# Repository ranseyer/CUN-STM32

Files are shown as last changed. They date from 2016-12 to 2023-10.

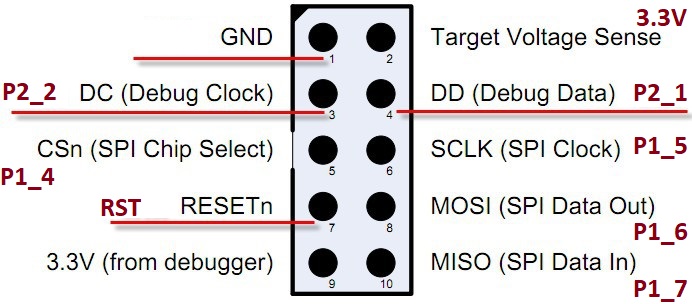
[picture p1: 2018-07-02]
HW-MAPLE-Large/AddOns/RasPi-UART__Zigbee-CC2530/Zigbee/smartrf04eb-pinout.jpg

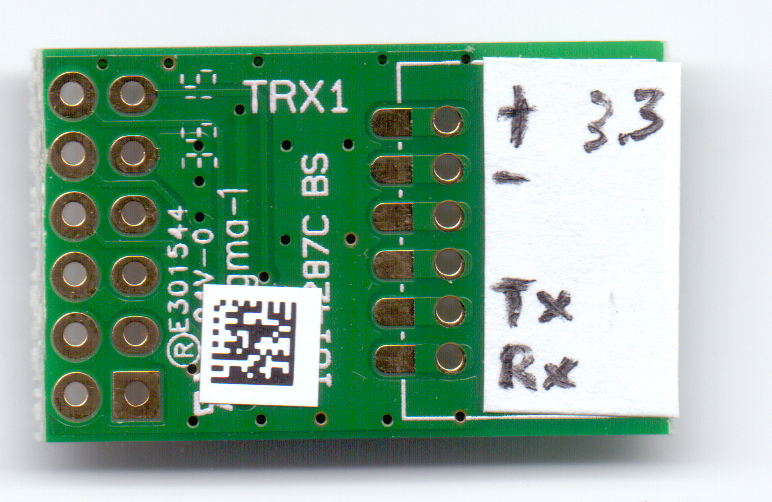
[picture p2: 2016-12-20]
Datasheets/HM_MOD_UART-Pinout.png

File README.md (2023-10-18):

View this project on [CADLAB.io](https://cadlab.io/project/1060). 

# CUN-STM32
The MAPLE-CUL is an ARM based RF Transceiver w/wo LAN for 433 or 868 MHz

- based on the STM32 / MAPLE Microcontroller
- Up to 4 Transceiver-Modules
- 2 Free UARTs for other AddOns / Transceiver or so
- 1 UART for WLAN Connection or debugging

-a lot of HW-AddOns are availble

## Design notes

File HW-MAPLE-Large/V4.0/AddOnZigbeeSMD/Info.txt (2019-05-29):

CC2530 Drahtlose Modul Zigbee Modul SZ1Zigbee 3,0-3,6 v 2,405-2,485 ghz
z.B. von Red Yellow Store
https://de.aliexpress.com/item/1861120386.html

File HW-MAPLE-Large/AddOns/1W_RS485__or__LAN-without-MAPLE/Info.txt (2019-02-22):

This AddOn hast two main functions:

Using Maple-CUL-AddOns without MAPLE-CUL
========================================
A) Base: USR-TCP232-E2 wit two UARTs or hopefully T2 (only one UART)
Important: This Board with LAN Module comes on top of all others...

MAPLE-CUL AddOn for OneWire and RS485
A) Onewire with DS2480 at the last UART of the MAPLE (UART2 can handle 5V without Levelshifter)
B) RS485 via Arduino and MAX487 or similar

Status: Not tested.

Todo: Check of separation of the connectors for RS485 and OneWire for parallel usage...

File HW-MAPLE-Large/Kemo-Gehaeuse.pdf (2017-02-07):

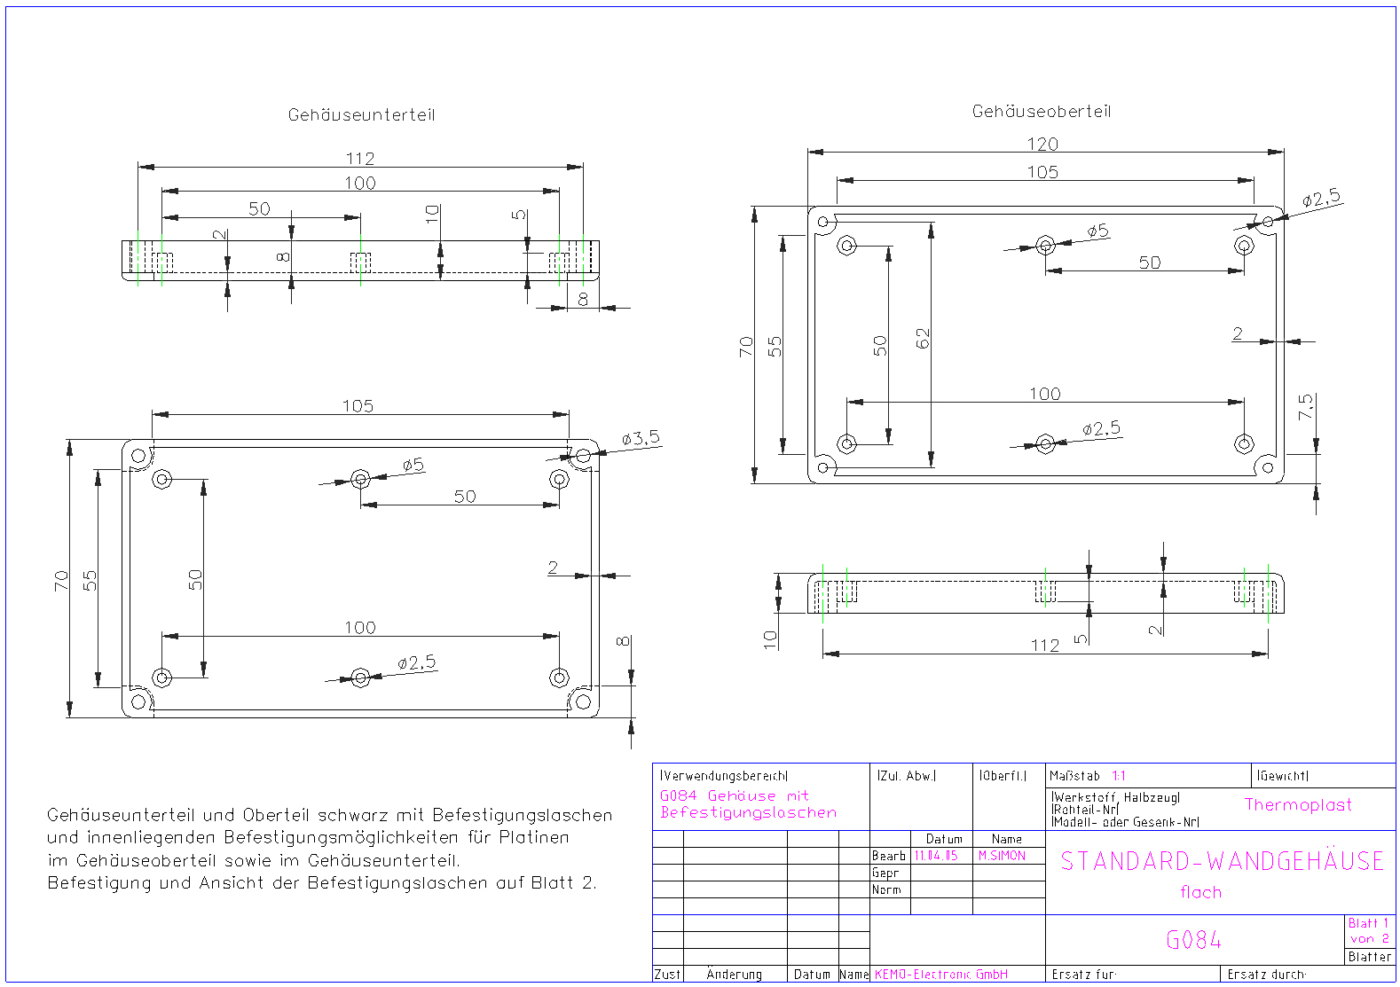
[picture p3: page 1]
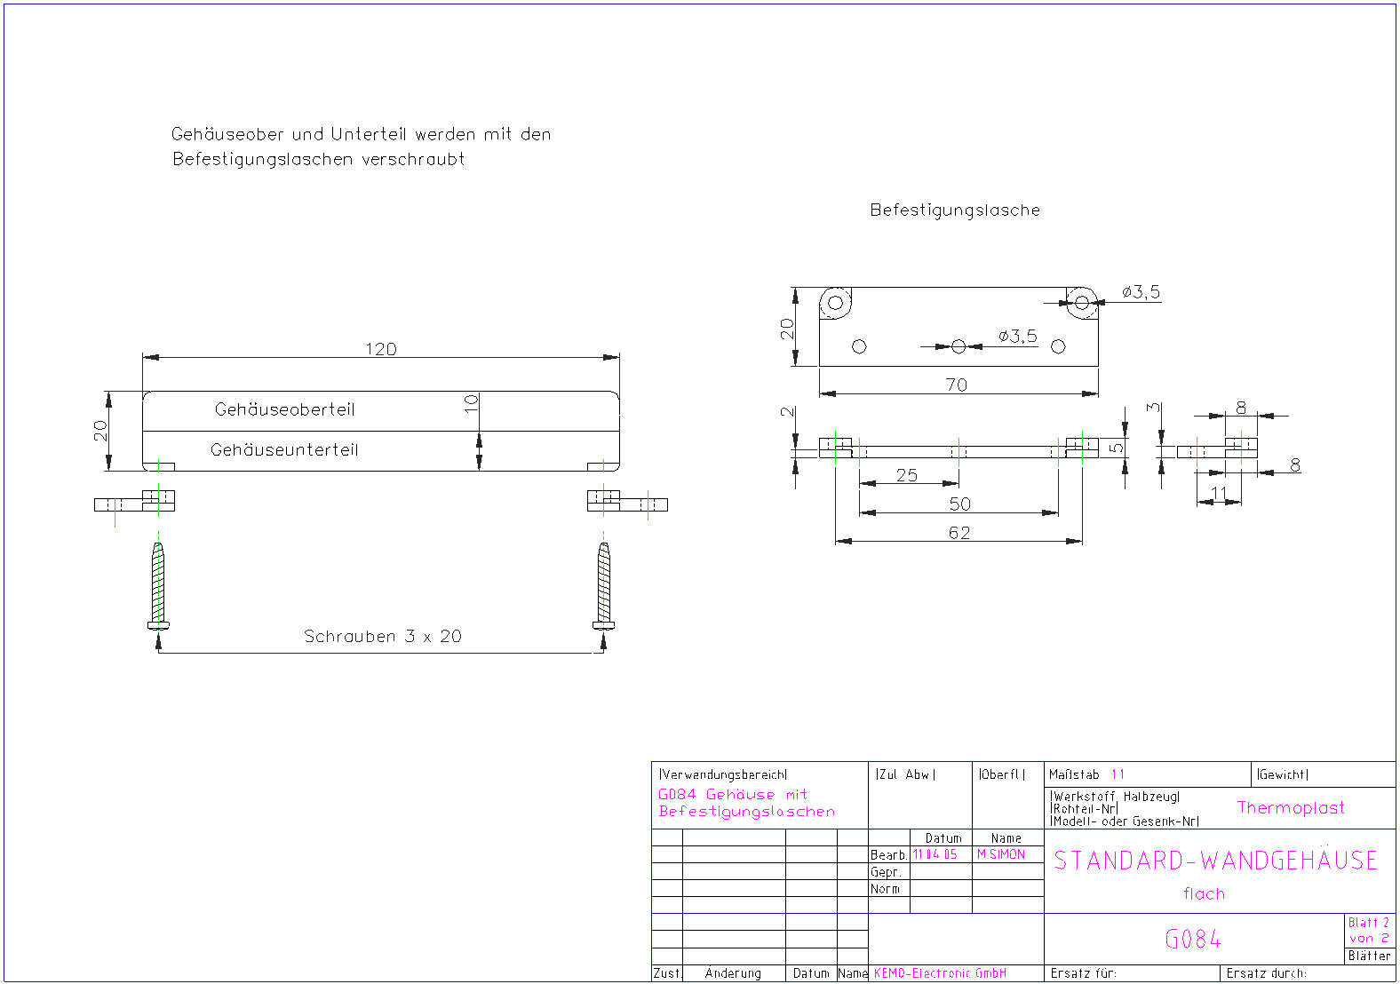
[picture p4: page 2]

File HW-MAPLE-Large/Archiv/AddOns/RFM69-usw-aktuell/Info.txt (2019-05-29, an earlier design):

Bei V1.4 gehen rx und TX auf verschiedene UARTs. Es muss daher einer der beiden Pins an den RX/TX-Sel Jumpern auf den anderen UART gelegt werden, so dass der Arduino nur mit einem UART kommuniziert.

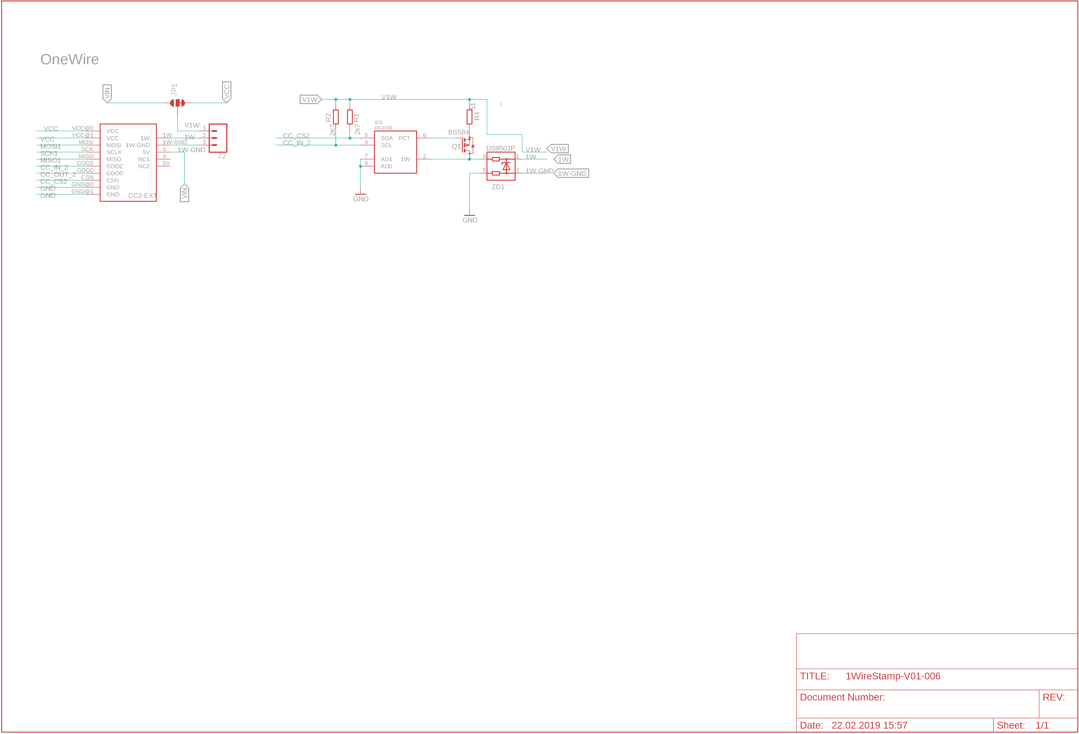
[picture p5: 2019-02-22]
HW-MAPLE-Large/Stamps/1Wire-Stamp/Schematic.png

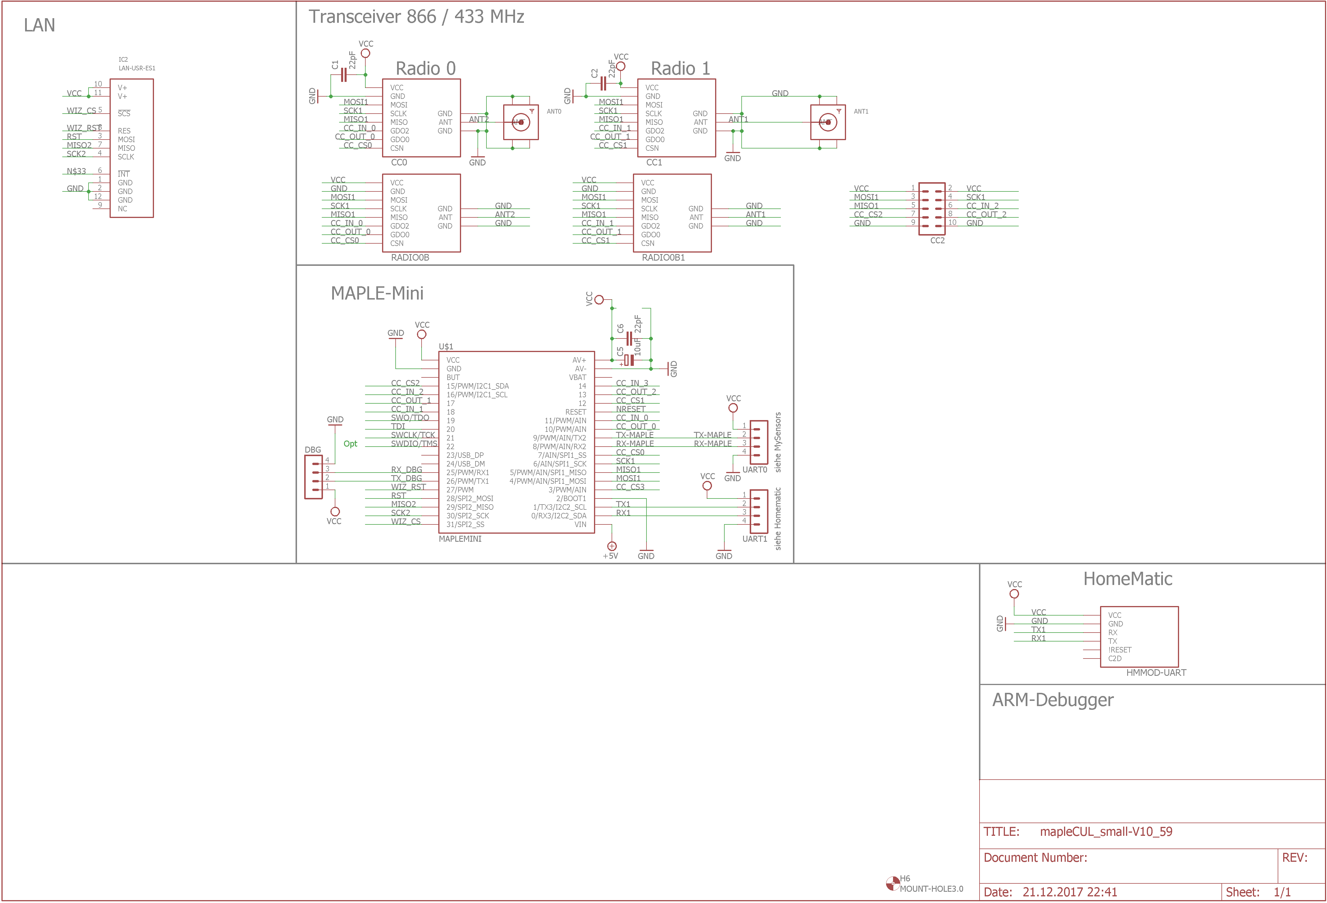
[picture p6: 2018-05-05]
HW-MAPLE-Small/Schematic-V10.png

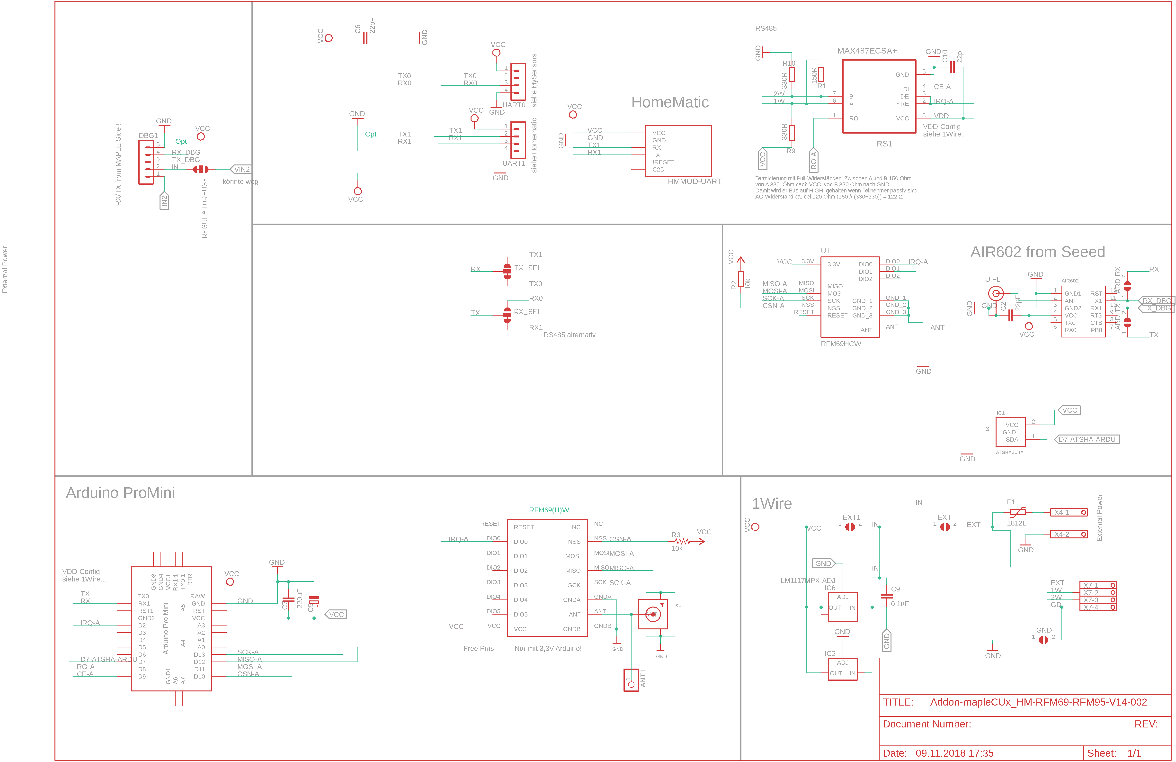
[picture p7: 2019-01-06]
HW-MAPLE-Large/AddOns/RFM69-usw-aktuell/schematic.png

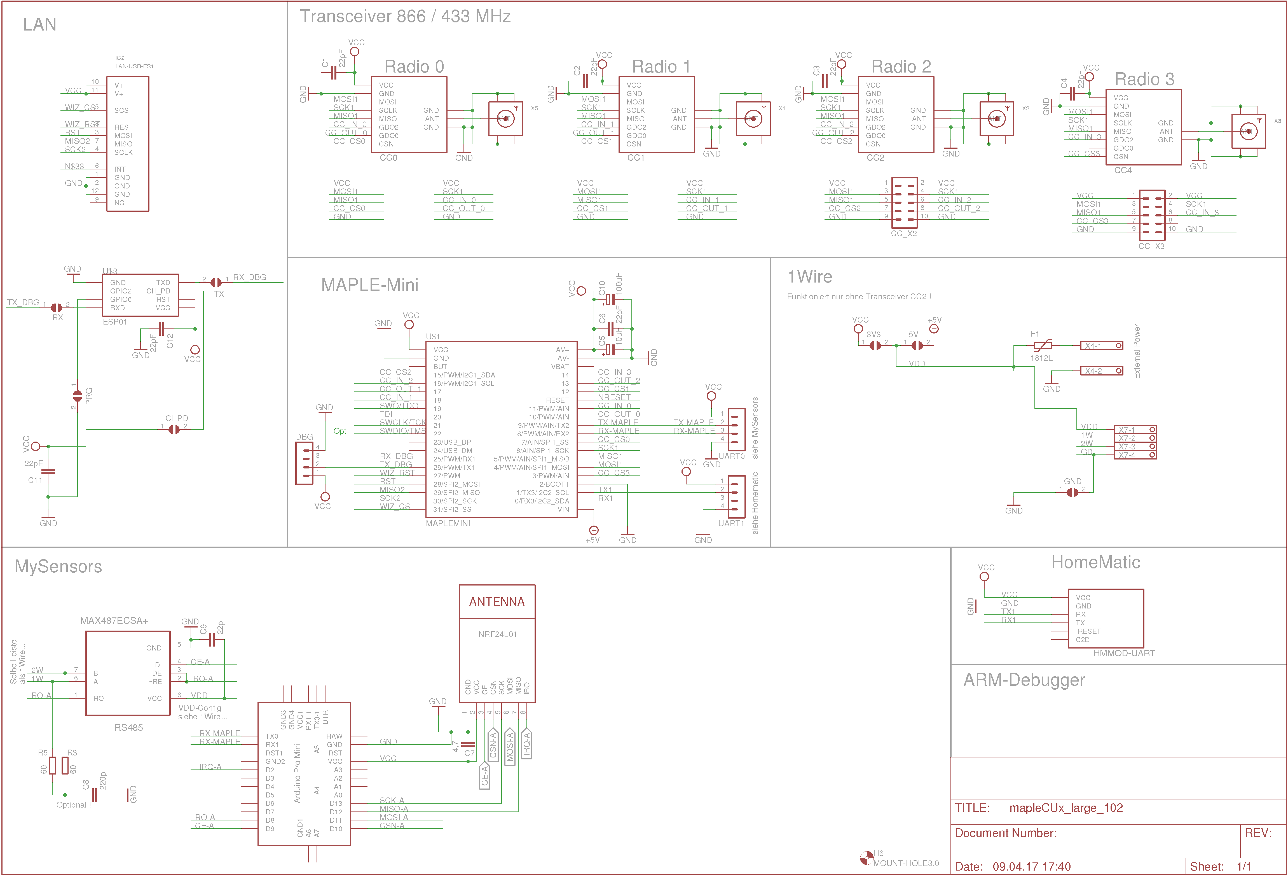
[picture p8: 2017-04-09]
HW-MAPLE-Large/Schematic-V102.png

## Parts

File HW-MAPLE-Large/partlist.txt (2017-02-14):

Partlist

Exported from mapleCUx_large_041.sch at 14.02.17 21:07

EAGLE Version 7.3.0 Copyright (c) 1988-2015 CadSoft

Assembly variant: 

Part       Value             Device            Package            Library         Sheet

C1         22pF              C-EUC0805         C0805              rcl             1
C2         22pF              C-EUC0805         C0805              rcl             1
C3         22pF              C-EUC0805         C0805              rcl             1
C4         22pF              C-EUC0805         C0805              rcl             1
C5         10uF              C-EUC1210         C1210              rcl             1
C6         22pF              C-EUC0805         C0805              rcl             1
C7         4,7               C-EUC1210         C1210              rcl             1
C31        100n              C-EUC0805         C0805              rcl             1
C32        100n              C-EUC0805         C0805              rcl             1
CC0        CC1101_MODULE1SMD CC1101_MODULE1SMD CC1101_MODULE1_SMD wireless        1
CC1        CC1101_MODULE1SMD CC1101_MODULE1SMD CC1101_MODULE1_SMD wireless        1
CC2        CC1101_MODULE1SMD CC1101_MODULE1SMD CC1101_MODULE1_SMD wireless        1
CC4        CC1101_MODULE1SMD CC1101_MODULE1SMD CC1101_MODULE1_SMD wireless        1
CC_X0                        MA05-2            MA05-2             con-lstb        1
CC_X1                        MA05-2            MA05-2             con-lstb        1
CC_X2                        MA05-2            MA05-2             con-lstb        1
CC_X4                        MA05-2            MA05-2             con-lstb        1
CTX-DB     1365-10           1365-10           1365-10            con-leotronics  1
DBG                          MA04-1            MA04-1             con-lstb        1
IC31       ATMEGA168-TQFP    ATMEGA168-TQFP    TQFP32-08          atmel           1
LED32                        LEDCHIPLED_0805   CHIPLED_0805       led             1
NRF24L01+  NRF24L01+         WIRELESS-NRF24L01 WIRELESS-NRF24L01  diy-modules     1
R32        1k                R-EU_R0805        R0805              rcl             1
R34                          R-EU_R0805        R0805              rcl             1
U$1        MAPLEMINI         MAPLEMINI         20-DIP             maplemini-small 1
U$2        ABK-PRO-MINI      ABK-PRO-MINI      ABK-PRO-MINI       Arduino-clone   1
UART0                        MA04-1            MA04-1             con-lstb        1
UART1                        MA04-1            MA04-1             con-lstb        1
W5100                        FE05-2            FE05-2             con-lsta        1
W5500NIREN                   MA05-2            MA05-2             con-lstb        1
X1         SMA               SMA               SMA                sma             1
X2         SMA               SMA               SMA                sma             1
X3         SMA               SMA               SMA                sma             1
X4         SMA               SMA               SMA                sma             1
X31        M03X2             M03X2             2X03-1.27MM_SMD    mechanics       1

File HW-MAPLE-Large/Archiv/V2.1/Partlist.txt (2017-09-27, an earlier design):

Partlist

Exported from mapleCUx_large_210.brd at 27.09.17 18:10

EAGLE Version 7.3.0 Copyright (c) 1988-2015 CadSoft

Assembly variant: 

Part       Value               Package            Library                     Position (mil)        Orientation

3V3                            SJ                 jumper                      (3825 750)            MR180
5V                             SJ                 jumper                      (3825 900)            MR0
ANT        MICRO RF            1X01               SparkFun-Connectors         (1900 200)            R0
C1         22pF                C0805              rcl                         (675 1100)            R0
C2         22pF                C0805              rcl                         (1842.75591 907.28346) R90
C3         22pF                C0805              rcl                         (2714.37008 1725)     MR180
C4         22pF                C0805              rcl                         (2690.31496 1075)     R0
C5         220uF               E5-8,5             rcl                         (2925 650)            R270
C6         22pF                C0805              rcl                         (175 2189.37008)      R180
C7                             C1812              rcl                         (2850 650)            R90
C8         220p                C0805              rcl                         (2481.69291 1907.67717) MR90
C9         22p                 C0805              rcl                         (3025 1940.94488)     MR270
C11        22pF                C0805              rcl                         (852.91339 887.59843) R270
C12        22pF                C0805              rcl                         (3650 1100)           R180
C14        30pf                0805               doug                        (800 200)             MR270
C15        30pf                0805               doug                        (800 375)             MR90
C31        100n                C0805              rcl                         (850 575)             MR0
C32        100n                C0805              rcl                         (1000 550)            MR270
CC0        CC1101              CC1101_MODULE1_SMD wireless                    (175 975)             R270
CC1        CC1101_MODULE1SMD   CC1101_MODULE1_SMD wireless                    (3150 975)            R270
CC2        CC1101_MODULE1SMD   CC1101_MODULE1_SMD wireless                    (1175 975)            R270
CC2-EXT    CC1101_MODULE3_DIL  CC1101_MODULE3_DIL wireless                    (1254.72441 1251.5748) R270
CC3        CC1101_MODULE1SMD   CC1101_MODULE1_SMD wireless                    (2175 975)            R270
CC3-EXT    CC1101_MODULE3_DIL  CC1101_MODULE3_DIL wireless                    (1944.68504 1256.88976) R270
CHPD                           SJ                 jumper                      (1850 600)            MR180
DBG                            MA04-1             con-lstb                    (1400 1650)           R270
F1         1812L               1812L              ptc-littlefuse              (3760 1745)           MR180
F2         1812L               1812L              ptc-littlefuse              (3850 525)            R270
GND                            SJ                 jumper                      (3825 1025)           MR180
HMMOD-UART HM-MOD-UARTDIL      HM-MOD-UART-DIL    wireless                    (3090 1485)           MR90
IC2        LAN-USR-ES1         USR-ES1            Martin-Communication        (330 1645)            R90
IC31       ATMEGA168-TQFP      TQFP32-08          atmel                       (400 550)             MR90
L1                             WE-KI_0805A        EAGLE-EMC_COMPONENTS-rev17a (2204.72441 2165.35433) R270
NRF24L01+  NRF24L01+           WIRELESS-NRF24L01  diy-modules                 (2600 1800)           R0
PRG                            SJ                 jumper                      (1850 750)            MR0
R1                             SJ_2               jumper                      (1025 1125)           MR90
R2         10k                 0805               doug                        (825 750)             MR90
R3         60                  R0805              rcl                         (3275 1250)           MR270
R4         1M                  0805               doug                        (1025 150)            MR0
R5         60                  R0805              rcl                         (3450 1275)           MR180
R34                            R0805              rcl                         (975 725)             MR180
RADIO0B    CC1101_MODULE1SMALL CC1101_MODULE1_SMD Martin-Communication        (240 815)             R270
RADIO1B    CC1101_MODULE1SMALL CC1101_MODULE1_SMD Martin-Communication        (3210 820)            R270
RADIO2B    CC1101_MODULE1SMALL CC1101_MODULE1_SMD Martin-Communication        (1240 820)            R270
RADIO3B    CC1101_MODULE1SMALL CC1101_MODULE1_SMD Martin-Communication        (2240 820)            R270
RS485      MAX487ECSA+         SOIC127P600X175-8N Maxim_By_element14_Batch_1  (2760.62992 1915.94488) MR180
RX                             SJ                 jumper                      (2050 750)            MR180
T1                             SJ_2               jumper                      (900 1125)            MR90
TX                             SJ                 jumper                      (2050 600)            MR180
U$1        MAPLEMINI           20-DIP             maplemini-small             (997.5 1645.62992)    R0
U$2        ABK-PRO-MINI        ABK-PRO-MINI       Arduino-clone               (3200 2002.79528)     R270
U$3        ESP01               ESP01              esp8266modules              (3250 1150)           R270
U1         RFM69HCW            RFM69HCW-XXXS2     doug                        (1425 600)            MR270
UART0                          MA04-1             con-lstb                    (1475 2200)           R0
UART1                          MA04-1             con-lstb                    (950 2200)            R0
X1                             SMA_EDGELAUNCH     adafruit                    (3425 0)              R90
X2                             SMA_EDGELAUNCH     adafruit                    (1400 0)              R90
X3                             SMA_EDGELAUNCH     adafruit                    (2400 0)              R90
X4         1751248             1751248            con-phoenix-350             (3800 1975)           R270
X5                             SMA_EDGELAUNCH     adafruit                    (400 0)               R90
X7         1751264             1751264            con-phoenix-350             (3800 1375)           R270
X8                             SMA_EDGELAUNCH_UFL adafruit                    (1900 0)              R90
X31        M03X2               2X03-1.27MM_SMD    mechanics                   (925 125)             R90
Y2         8MHZ                CRYSTAL-TXC-7A     SparkFun-FreqCtrl           (1000 325)            MR270

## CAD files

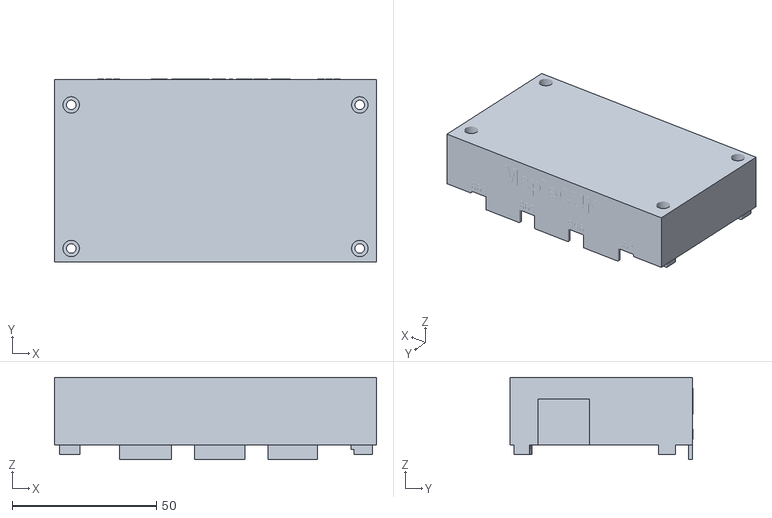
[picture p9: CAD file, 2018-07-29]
HW-MAPLE-Large/Gehaeuse/by_Eistee/MapleCUN_top.stl
111.7 x 63.4 x 28.6

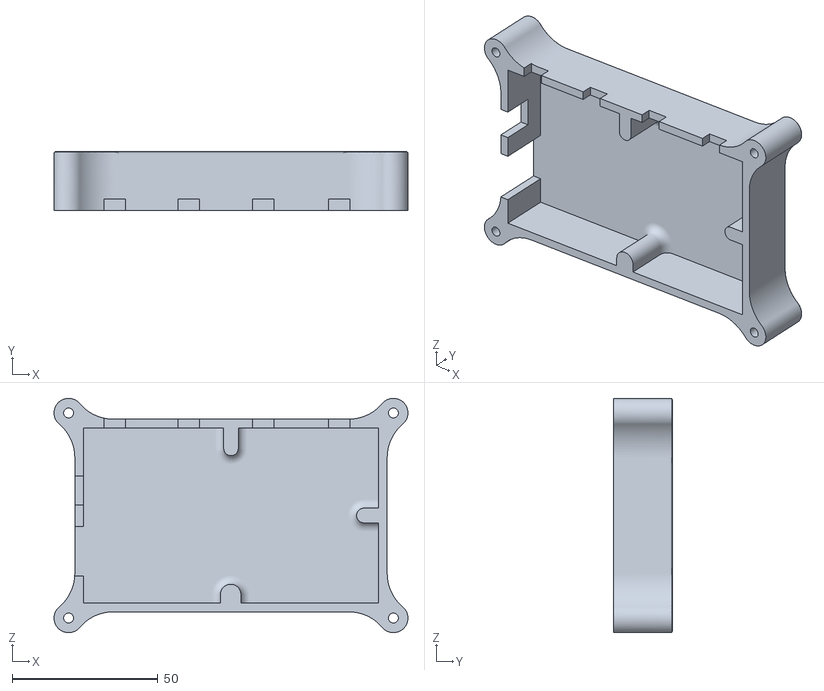
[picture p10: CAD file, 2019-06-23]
HW-MAPLE-Large/Gehaeuse/Gloob/Top_v28.stl
121.2 x 20.1 x 80.2

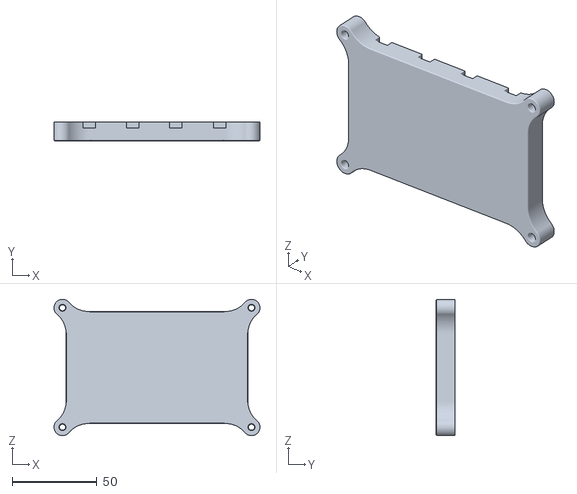
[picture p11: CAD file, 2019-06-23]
HW-MAPLE-Large/Gehaeuse/Gloob/Bottom_v28.stl
121.2 x 11.0 x 80.2

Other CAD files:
HW-MAPLE-Large/Gehaeuse/Gloob/Top-FreeCAD-Import-V28.FCStd
HW-MAPLE-Large/Gehaeuse/Gloob/Top_v28_without_ethernet.stl
HW-MAPLE-Large/Gehaeuse/by_Eistee/MapleCUN_Gehäuse.f3d

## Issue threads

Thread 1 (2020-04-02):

AddOnArduino-RFMx RX/TX vertauscht

matztam, 2020-04-02:
Folgende Platinen kommen zum Einsatz:
- mapleCUx_large_4.1-018.brd
- V4-MySensors-LoRa-V006.brd

Auf dem AddOnArduino-RFMx ist ein Arduino Pro Mini (ATmega 328p 5V/16MHz) verlötet.

Damit die vom Addon ausgegebenen Daten auch vom MapleCun übertragen wurden, musste ich RX und TX mit einem Kabel vertauschen/kreuzen. Ich habe es an beiden UARTs getestet.

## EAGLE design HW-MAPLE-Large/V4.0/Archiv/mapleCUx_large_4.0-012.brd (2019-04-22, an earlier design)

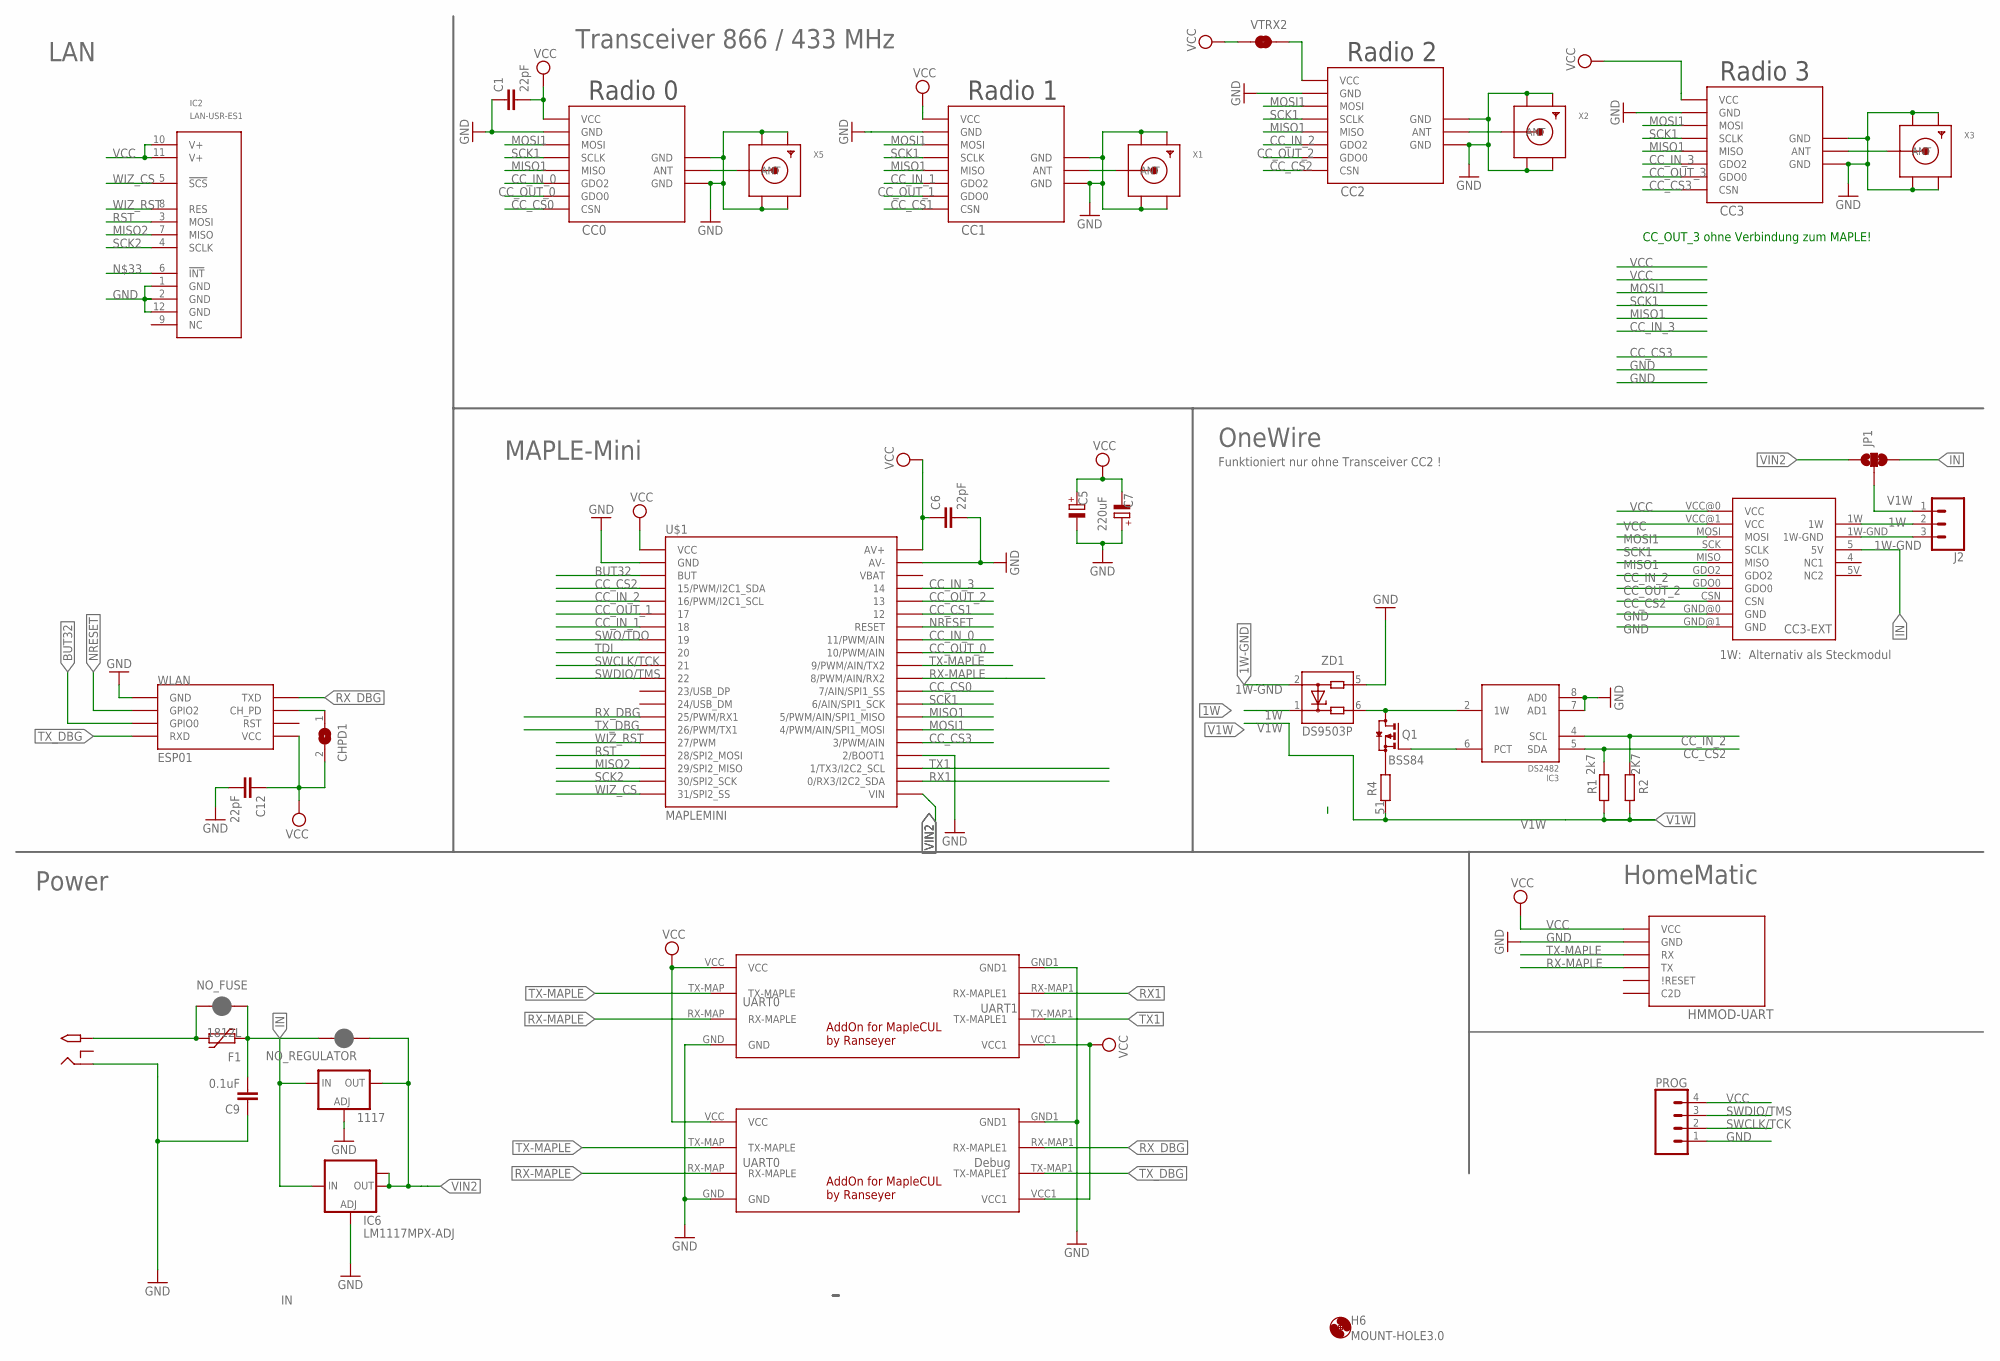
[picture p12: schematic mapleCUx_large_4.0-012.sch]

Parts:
1117: LD117ADT50TR; DPACK
C1, C6, C12: 22pF; C0805
C5: 220uF; E5-8,5
C7: CPOL-EUSMCE; SMC_E
C9: 0.1uF; C1206
CC0: CC1101; CC1101_MODULE1_SMD
CC1, CC2, CC3: CC1101_MODULE1SMD; CC1101_MODULE1_SMD
CC3-EXT: ONEWIRE-MODULE; ONEWIRE_CC1101_MODULE3_DIL
CHPD1: SJ
F1: 1812L
H6: MOUNT-HOLE3.0; 3,0
HMMOD-UART: HM-MOD-UARTDIL; HM-MOD-UART-DIL
IC2: LAN-USR-ES1; USR-ES1
IC3: DS2482; SO08
IC6: LM1117MPX-ADJ; SOT223
J2: CONN_03LONGPADS; 1X03_LONGPADS
JP1: JUMPER-SMT_3_1-NC_TRACE_SILK; SMT-JUMPER_3_1-NC_TRACE_SILK
NO_FUSE: JUMPER-SMT_2_NC_PASTE_NO-SILK; SMT-JUMPER_2_NC_PASTE_NO-SILK
NO_REGULATOR: JUMPER-SMT_2_NC_PASTE_NO-SILK; SMT-JUMPER_2_NC_PASTE_NO-SILK
PROG: CONN_04LOCK; 1X04_LOCK
Q1: BSS84; SOT23
R1: 2k7; R0805
R2: 2K7; R0805
R4: 51; R0805
U$1: MAPLEMINI; 20-DIP
U$2: 2.1MMJACKTHM; PJ-102A
U$3, U$4: MAPLE-CUL-ADDON-V01; MAPLE-CUL-V01
VTRX2: JUMPER-SMT_2_NC_TRACE_SILK; SMT-JUMPER_2_NC_TRACE_SILK
WLAN: ESP01
X1, X2, X3, X5: SMACONNECTOR_EDGE; SMA_EDGELAUNCH
ZD1: DS9503P; TSOC6

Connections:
1W: CC3-EXT.1W, J2.2, ZD1.1
1W-GND: CC3-EXT.1W-GND, J2.3, ZD1.2
ANT0: CC0.ANT, X5.P (ANT)
ANT1: CC1.ANT, X1.P (ANT)
ANT2: CC2.ANT, X2.P (ANT)
ANT3: CC3.ANT, X3.P (ANT)
BUT32: U$1.3 (BUT), WLAN.GPIO0
CC_CS0: CC0.CSN, U$1.29 (7/AIN/SPI1_SS)
CC_CS1: CC1.CSN, U$1.35 (12)
CC_CS2: CC2.CSN, CC3-EXT.CSN, IC3.5 (SDA), R1.2, U$1.4 (15/PWM/I2C1_SDA)
CC_CS3: CC3.CSN, U$1.25 (3/PWM/AIN)
CC_IN_0: CC0.GDO2, U$1.33 (11/PWM/AIN)
CC_IN_1: CC1.GDO2, U$1.7 (18)
CC_IN_2: CC2.GDO2, CC3-EXT.GDO2, IC3.4 (SCL), R2.2, U$1.5 (16/PWM/I2C1_SCL)
CC_IN_3: CC3.GDO2, U$1.37 (14)
CC_OUT_0: CC0.GDO0, U$1.32 (10/PWM/AIN)
CC_OUT_1: CC1.GDO0, U$1.6 (17)
CC_OUT_2: CC2.GDO0, CC3-EXT.GDO0, U$1.36 (13)
CC_OUT_3: CC3.GDO0
GND: 1117.1 (ADJ), C1.1, C5.-, C6.2, C7.+, C9.1, C12.2, CC0.GND@0 (GND), CC0.GND@1 (GND), CC0.GND@2 (GND), CC1.GND@0 (GND), CC1.GND@1 (GND), CC1.GND@2 (GND), CC2.GND@0 (GND), CC2.GND@1 (GND), CC2.GND@2 (GND), CC3.GND@0 (GND), CC3.GND@1 (GND), CC3.GND@2 (GND), CC3-EXT.GND@0 (GND), CC3-EXT.GND@1 (GND), HMMOD-UART.2 (GND), IC2.1 (GND), IC2.2 (GND), IC2.12 (GND), IC3.3 (GND), IC3.7 (AD1), IC3.8 (AD0), IC6.1 (ADJ), PROG.1, U$1.2 (GND), U$1.24 (2/BOOT1), U$1.39 (AV-), U$2.RING, U$3.GND, U$3.GND1, U$4.GND, U$4.GND1, WLAN.GND, X1.GND@1 (GND4), X1.GND@2 (GND3), X1.GND@3 (GND2), X1.GND@4 (GND1), X2.GND@1 (GND4), X2.GND@2 (GND3), X2.GND@3 (GND2), X2.GND@4 (GND1), X3.GND@1 (GND4), X3.GND@2 (GND3), X3.GND@3 (GND2), X3.GND@4 (GND1), X5.GND@1 (GND4), X5.GND@2 (GND3), X5.GND@3 (GND2), X5.GND@4 (GND1), ZD1.5
IN: 1117.3 (IN), C9.2, CC3-EXT.5 (5V), F1.P$1 (1), IC6.3 (IN), JP1.3, NO_FUSE.1, NO_REGULATOR.2
MISO1: CC0.MISO, CC1.MISO, CC2.MISO, CC3.MISO, CC3-EXT.MISO, U$1.27 (5/PWM/AIN/SPI1_MISO)
MISO2: IC2.7 (MISO), U$1.18 (29/SPI2_MISO)
MOSI1: CC0.MOSI, CC1.MOSI, CC2.MOSI, CC3.MOSI, CC3-EXT.MOSI, U$1.26 (4/PWM/AIN/SPI1_MOSI)
unnamed: CC2.VCC, VTRX2.2
unnamed: CHPD1.1, WLAN.CH_PD
unnamed: IC3.6 (PCT), Q1.1 (G)
unnamed: IC3.2 (1W), Q1.3 (D), ZD1.6
unnamed: Q1.2 (S), R4.1
NRESET: U$1.34 (RESET), WLAN.GPIO2
RST: IC2.3 (MOSI), U$1.17 (28/SPI2_MOSI)
RX1: U$1.22 (0/RX3/I2C2_SDA), U$3.RX-MAP1 (RX-MAPLE1)
RX-MAPLE: HMMOD-UART.5 (TX), U$1.30 (8/PWM/AIN/RX2), U$3.RX-MAP (RX-MAPLE), U$4.RX-MAP (RX-MAPLE)
RX_DBG: U$1.14 (25/PWM/RX1), U$4.RX-MAP1 (RX-MAPLE1), WLAN.TX (TXD)
SCK1: CC0.SCLK, CC1.SCLK, CC2.SCLK, CC3.SCLK, CC3-EXT.SCK (SCLK), U$1.28 (6/AIN/SPI1_SCK)
SCK2: IC2.4 (SCLK), U$1.19 (30/SPI2_SCK)
SWCLK/TCK: PROG.2, U$1.10 (21)
SWDIO/TMS: PROG.3, U$1.11 (22)
SWO/TDO: U$1.8 (19)
TDI: U$1.9 (20)
TX1: U$1.23 (1/TX3/I2C2_SCL), U$3.TX-MAP1 (TX-MAPLE1)
TX-MAPLE: HMMOD-UART.6 (RX), U$1.31 (9/PWM/AIN/TX2), U$3.TX-MAP (TX-MAPLE), U$4.TX-MAP (TX-MAPLE)
TX_DBG: U$1.15 (26/PWM/TX1), U$4.TX-MAP1 (TX-MAPLE1), WLAN.RX (RXD)
V1W: IC3.1 (VDD), J2.1, JP1.2, R1.1, R2.1, R4.2
VCC: C1.2, C5.+, C6.1, C7.-, C12.1, CC0.VCC, CC1.VCC, CC3.VCC, CC3-EXT.VCC@0 (VCC), CC3-EXT.VCC@1 (VCC), CHPD1.2, HMMOD-UART.1 (VCC), IC2.10 (V+), IC2.11 (V+), PROG.4, U$1.1 (VCC), U$1.40 (AV+), U$3.VCC, U$3.VCC1, U$4.VCC, U$4.VCC1, VTRX2.1, WLAN.VCC
VIN: F1.P$2 (2), NO_FUSE.2, U$2.TIP
VIN2: 1117.4 (OUT), IC6.2 (OUT), IC6.TAB (OUT1), JP1.1, NO_REGULATOR.1, U$1.21 (VIN)
WIZ_CS: IC2.5 (!SCS!), U$1.20 (31/SPI2_SS)
WIZ_RST: IC2.8 (RES), U$1.16 (27/PWM)

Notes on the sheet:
Radio 1
Radio 0
Radio 2
Radio 3
OneWire
Power
HomeMatic
MAPLE-Mini
Transceiver 866 / 433 MHz
LAN
CC_OUT_3 ohne Verbindung zum MAPLE!
Funktioniert nur ohne Transceiver CC2 !
1W: Alternativ als Steckmodul
UART0
Debug
UART1

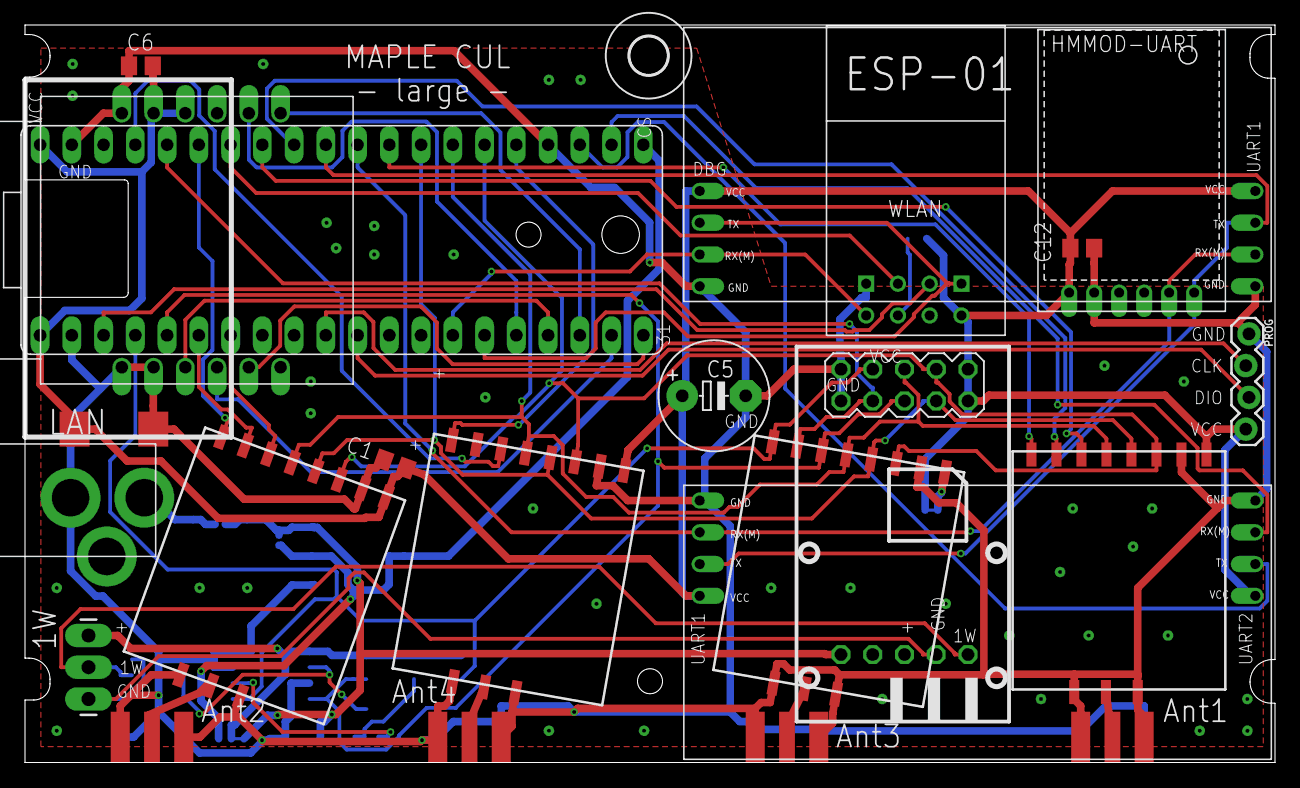
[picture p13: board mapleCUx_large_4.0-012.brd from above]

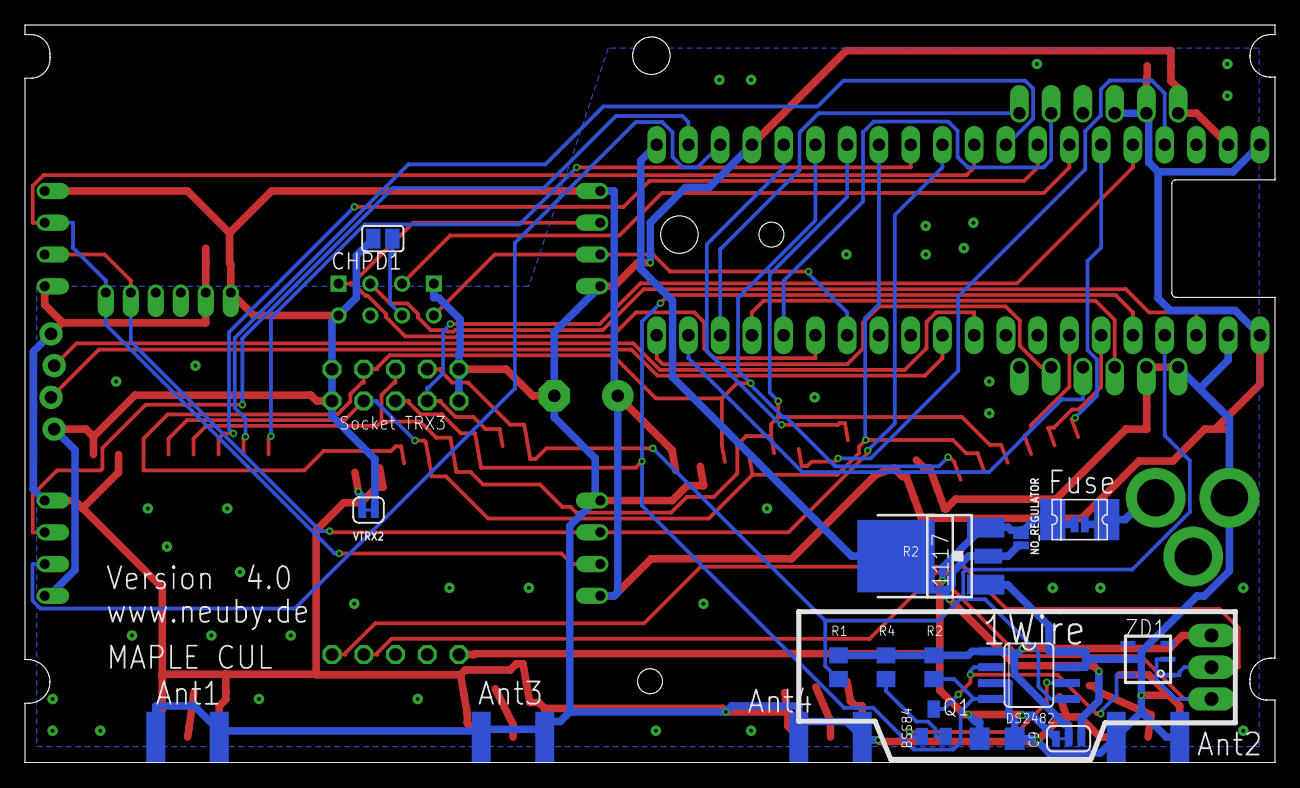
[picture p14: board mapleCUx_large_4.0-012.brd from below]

Board: 2 copper layers, 100.0 x 59.0 mm, 39 parts (15 on the bottom side), 46 nets.

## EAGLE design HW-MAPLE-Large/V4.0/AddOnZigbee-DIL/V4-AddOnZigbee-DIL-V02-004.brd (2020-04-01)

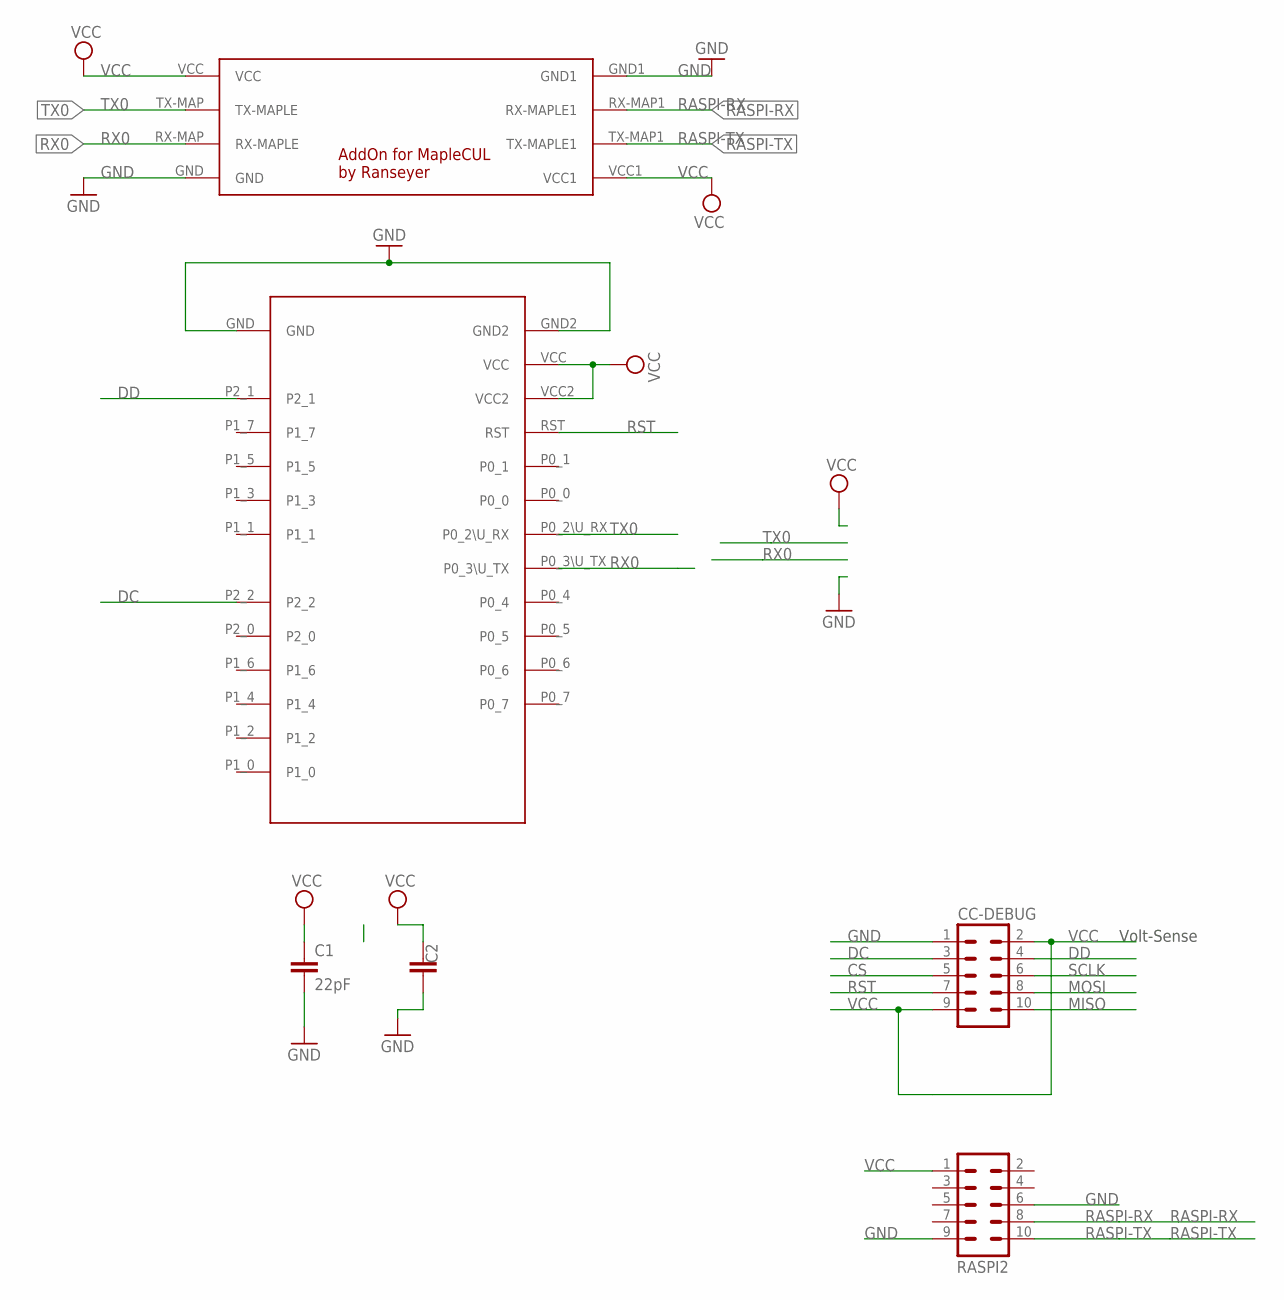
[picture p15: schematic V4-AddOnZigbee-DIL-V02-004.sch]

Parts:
C1: 22pF; C0805
C2: C-EUC1812; C1812
CC-DEBUG: CONN_05X2SHD_LOCK; 2X5-SHROUDED_LOCK
RASPI2: MA05-2
U$1: MAPLE-CUL-ADDON-V01; MAPLE-CUL-V01
U$3: CC2530_MODULE; CC2530_DIL

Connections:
CS: CC-DEBUG.5
DC: CC-DEBUG.3, U$3.P2_2
DD: CC-DEBUG.4, U$3.P2_1
GND: C1.2, C2.1, CC-DEBUG.1, RASPI2.6, RASPI2.9, U$1.GND, U$1.GND1, U$3.GND, U$3.GND2
MISO: CC-DEBUG.10
MOSI: CC-DEBUG.8
RASPI-RX: RASPI2.8, U$1.RX-MAP1 (RX-MAPLE1)
RASPI-TX: RASPI2.10, U$1.TX-MAP1 (TX-MAPLE1)
RST: CC-DEBUG.7, U$3.RST
RX0: U$1.RX-MAP (RX-MAPLE), U$3.P0_3\U_TX
SCLK: CC-DEBUG.6
TX0: U$1.TX-MAP (TX-MAPLE), U$3.P0_2\U_RX
VCC: C1.1, C2.2, CC-DEBUG.2, CC-DEBUG.9, RASPI2.1, U$1.VCC, U$1.VCC1, U$3.VCC, U$3.VCC2

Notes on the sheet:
Volt-Sense

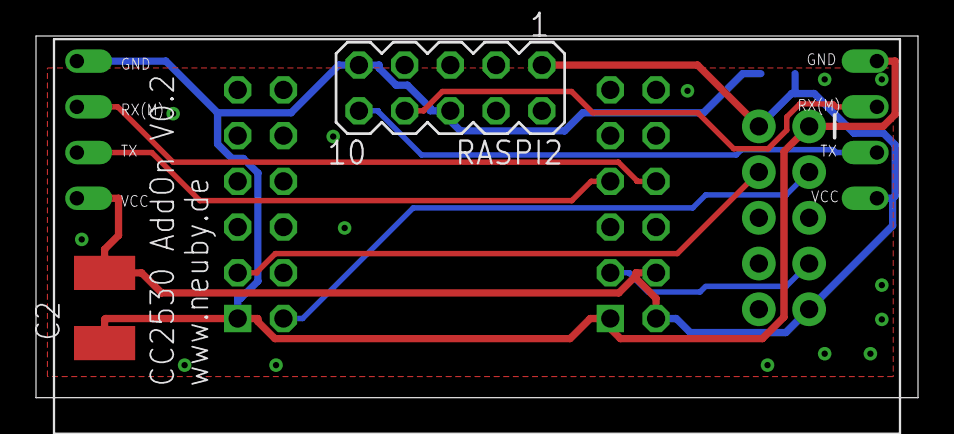
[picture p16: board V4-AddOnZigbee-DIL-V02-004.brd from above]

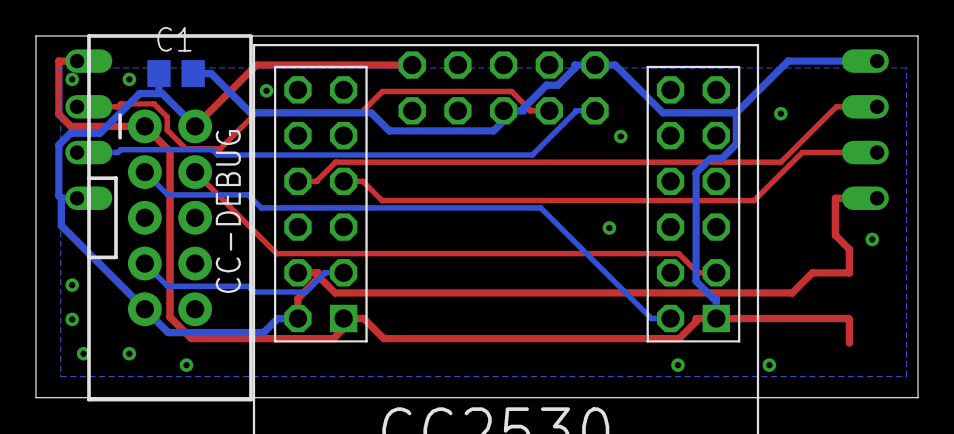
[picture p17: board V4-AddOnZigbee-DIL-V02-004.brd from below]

Board: 2 copper layers, 49.0 x 20.1 mm, 6 parts (3 on the bottom side), 9 nets.

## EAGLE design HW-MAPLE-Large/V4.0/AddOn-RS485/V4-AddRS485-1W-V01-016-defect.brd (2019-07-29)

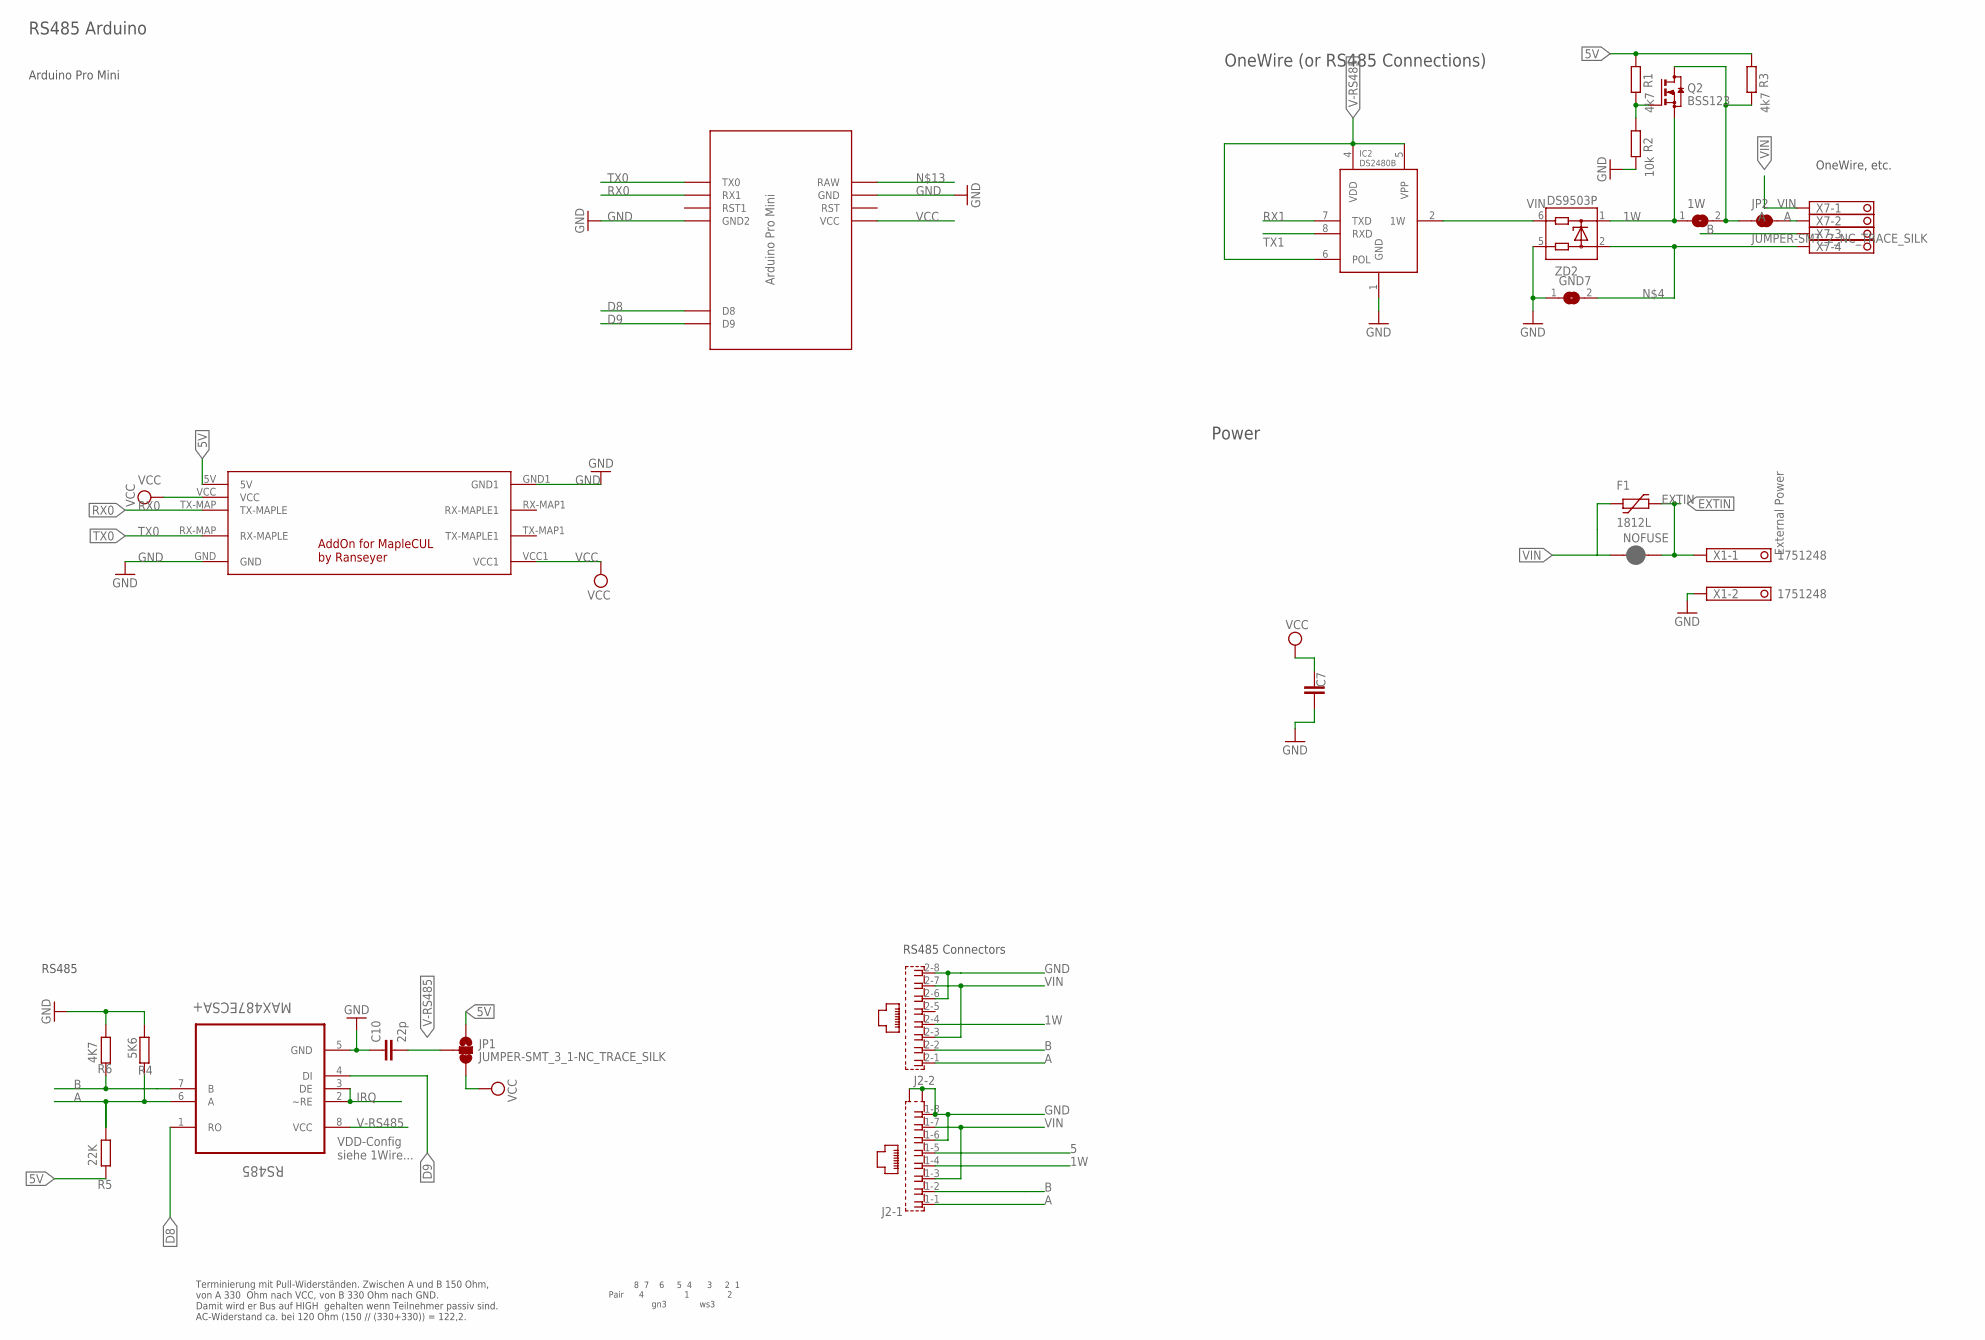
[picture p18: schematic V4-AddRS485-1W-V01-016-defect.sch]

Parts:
1W: SJ
C7: C-EUC1812; C1812
C10: 22p; C0805
F1: 1812L
GND7: SJ
IC2: DS2480B; SO08
J2: RJ45_2X_S
JP1: JUMPER-SMT_3_1-NC_TRACE_SILK; SMT-JUMPER_3_1-NC_TRACE_SILK
JP2: JUMPER-SMT_2_NC_TRACE_SILK; SMT-JUMPER_2_NC_TRACE_SILK
NOFUSE: JUMPER-SMT_2_NC_PASTE_NO-SILK; SMT-JUMPER_2_NC_PASTE_NO-SILK
Q2: BSS123; SOT23
R1, R3: 4k7; R0805
R2: 10k; R0805
R4: 5K6; R0805
R5: 22K; R0805
R6: 4K7; R0805
RS485: MAX487ECSA+; SOIC127P600X175-8N
U$2: MAPLE-CUL-ADDON-V01; MAPLE-CUL-V01
U$3: MARTIN-PRO-MINI-RS485
X1: 1751248
X7: 1751264
ZD2: DS9503P; TSOC6

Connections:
1W: 1W.1, J2.1-4 (4), J2.2-4 (4), Q2.2 (S), ZD2.1
5: J2.1-5 (5)
5V: JP1.1, R1.1, R3.1, R5.1, U$2.5V
A: 1W.2, J2.1-1 (1), J2.2-1 (1), JP2.1, JP2.2, Q2.3 (D), R3.2, R4.2, R5.2, RS485.6 (A), X7.2
B: J2.1-2 (2), J2.2-2 (2), R6.1, RS485.7 (B), X7.3
D8: RS485.1 (RO), U$3.D8
D9: RS485.4 (DI), U$3.D9
EXTIN: F1.P$2 (2), NOFUSE.2, X1.1
GND: C7.1, C10.1, GND7.1, IC2.1 (GND), J2.1-6 (6), J2.1-8 (8), J2.2-6 (6), J2.2-8 (8), J2.G1 (S2), J2.G3 (S1), R2.2, R4.1, R6.2, RS485.5 (GND), U$2.GND, U$2.GND1, U$3.GND, U$3.GND1 (GND2), X1.2, ZD2.5
IRQ: RS485.2 (~RE), RS485.3 (DE)
unnamed: C10.2, JP1.2
unnamed: IC2.2 (1W), ZD2.6
unnamed: GND7.2, X7.4, ZD2.2
unnamed: Q2.1 (G), R1.2, R2.1
RX0: U$2.TX-MAP (TX-MAPLE), U$3.RX1
RX1: IC2.7 (TXD)
TX0: U$2.RX-MAP (RX-MAPLE), U$3.TX0
TX1: IC2.8 (RXD)
V-RS485: IC2.4 (VDD), IC2.5 (VPP), IC2.6 (POL), RS485.8 (VCC)
VCC: C7.2, JP1.3, U$2.VCC, U$2.VCC1, U$3.VCC
VIN: F1.P$1 (1), J2.1-3 (3), J2.1-7 (7), J2.2-3 (3), J2.2-7 (7), NOFUSE.1, X7.1

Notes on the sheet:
External Power
8 7 6 5 4 3 2 1 Pair 4 1 2 gn3 ws3
RS485 Connectors
OneWire, etc.
Arduino Pro Mini
RS485
VDD-Config siehe 1Wire...
Terminierung mit Pull-Widerständen. Zwischen A und B 150 Ohm, von A 330 Ohm nach VCC, von B 330 Ohm nach GND. Damit wird er Bus auf HIGH gehalten wenn Teilnehmer passiv sind. AC-Widerstand ca. bei 120 Ohm (150 // (330+330)) = 122,2.
OneWire (or RS485 Connections)
RS485 Arduino
Power

Board: 2 copper layers, 23 parts (4 on the bottom side), 18 nets, no tracks yet.

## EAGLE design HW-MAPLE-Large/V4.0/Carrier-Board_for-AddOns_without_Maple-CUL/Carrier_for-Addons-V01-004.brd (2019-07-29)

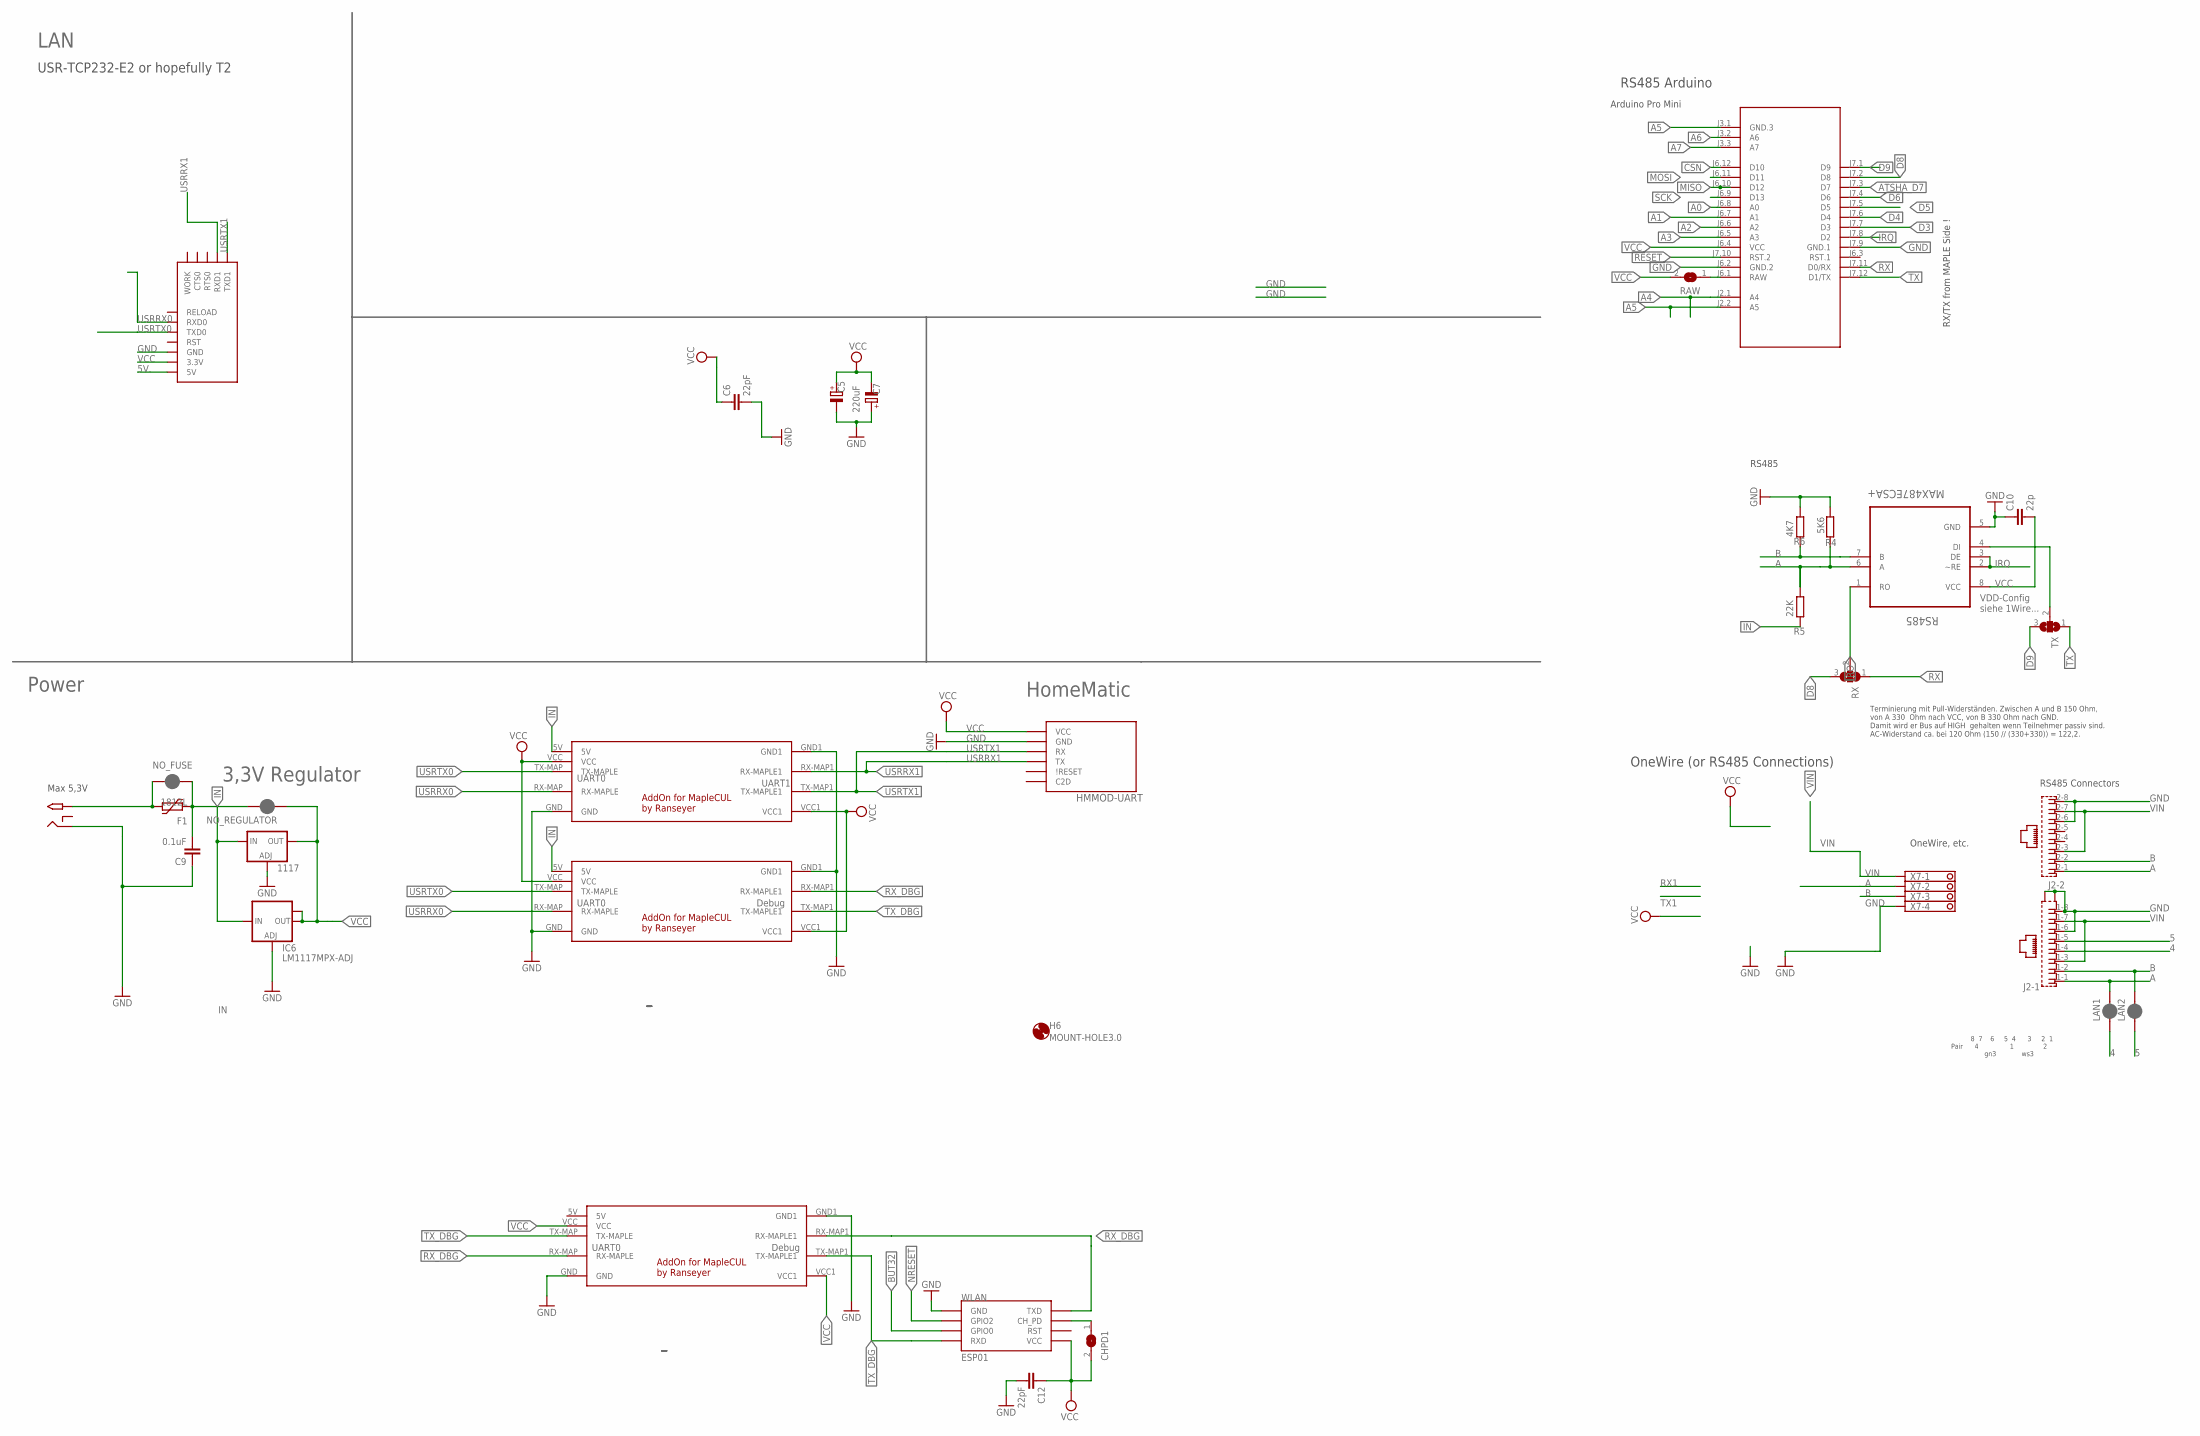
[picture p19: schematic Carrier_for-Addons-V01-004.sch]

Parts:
1117: LD117ADT50TR; DPACK
C5: 220uF; E5-8,5
C6, C12: 22pF; C0805
C7: CPOL-EUSMCE; SMC_E
C9: 0.1uF; C1206
C10: 22p; C0805
CHPD1: SJ
F1: 1812L
H6: MOUNT-HOLE3.0; 3,0
HMMOD-UART: HM-MOD-UARTDIL; HM-MOD-UART-DIL
IC6: LM1117MPX-ADJ; SOT223
J2: RJ45_2X_S
LAN1, LAN2: JUMPER-SMT_2_NC_PASTE_SILK; SMT-JUMPER_2_NC_PASTE_SILK
M1: ARDUINO-PRO-MINI-3.3V#NP; ARDUINO-PRO-MINI#NP
NO_FUSE: JUMPER-SMT_2_NC_PASTE_NO-SILK; SMT-JUMPER_2_NC_PASTE_NO-SILK
NO_REGULATOR: JUMPER-SMT_2_NC_PASTE_NO-SILK; SMT-JUMPER_2_NC_PASTE_NO-SILK
R4: 5K6; R0805
R5: 22K; R0805
R6: 4K7; R0805
RAW: SJ
RS485: MAX487ECSA+; SOIC127P600X175-8N
RX: SJ2W; SJ_2
TX: SJ2W; SJ_2
U$1, U$3, U$4: MAPLE-CUL-ADDON-V01; MAPLE-CUL-V01
U$2: 2.1MMJACKTHM; PJ-102A
U$5: USR-TCP232-E2
WLAN: ESP01
X7: 1751264

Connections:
4: J2.1-4 (4), LAN1.1
5: J2.1-5 (5), LAN2.1
5V.: U$5.5V
A: J2.1-1 (1), J2.2-1 (1), LAN1.2, R4.2, R5.2, RS485.6 (A), X7.2
A0: M1.J6.8 (A0)
A1: M1.J6.7 (A1)
A2: M1.J6.6 (A2)
A3: M1.J6.5 (A3)
A4: M1.J2.1 (A4)
A5: M1.J2.2 (A5), M1.J3.1 (GND.3)
A6: M1.J3.2 (A6)
A7: M1.J3.3 (A7)
ATSHA_D7: M1.J7.3 (D7)
B: J2.1-2 (2), J2.2-2 (2), LAN2.2, R6.1, RS485.7 (B), X7.3
BUT32: WLAN.GPIO0
CSN: M1.J6.12 (D10)
D3: M1.J7.7 (D3)
D4: M1.J7.6 (D4)
D5: M1.J7.5 (D5)
D6: M1.J7.4 (D6)
D8: M1.J7.2 (D8), RX.3
D9: M1.J7.1 (D9), TX.3
DI1: RS485.4 (DI), TX.2
GND: 1117.1 (ADJ), C5.-, C6.2, C7.+, C9.1, C10.1, C12.2, HMMOD-UART.2 (GND), IC6.1 (ADJ), J2.1-6 (6), J2.1-8 (8), J2.2-6 (6), J2.2-8 (8), J2.G1 (S2), J2.G3 (S1), M1.J6.2 (GND.2), M1.J7.9 (GND.1), R4.1, R6.2, RS485.5 (GND), U$1.GND, U$1.GND1, U$2.RING, U$3.GND, U$3.GND1, U$4.GND, U$4.GND1, U$5.GND, WLAN.GND, X7.4
IN: 1117.3 (IN), C9.2, F1.P$1 (1), IC6.3 (IN), NO_FUSE.1, NO_REGULATOR.2, R5.1, U$3.5V, U$4.5V
IRQ: M1.J7.8 (D2), RS485.2 (~RE), RS485.3 (DE)
MISO: M1.J6.10 (D12)
MOSI: M1.J6.11 (D11)
unnamed: CHPD1.1, WLAN.CH_PD
NRESET: WLAN.GPIO2
RAW1: M1.J6.1 (RAW), RAW.1
RESET: M1.J7.10 (RST.2)
RO: RS485.1 (RO), RX.2
RX: M1.J7.11 (D0/RX), RX.1
RX_DBG: U$1.RX-MAP (RX-MAPLE), U$1.RX-MAP1 (RX-MAPLE1), U$4.RX-MAP1 (RX-MAPLE1), WLAN.TX (TXD)
SCK: M1.J6.9 (D13)
TX: M1.J7.12 (D1/TX), TX.1
TX_DBG: U$1.TX-MAP (TX-MAPLE), U$1.TX-MAP1 (TX-MAPLE1), U$4.TX-MAP1 (TX-MAPLE1), WLAN.RX (RXD)
USRRX0: U$3.RX-MAP (RX-MAPLE), U$4.RX-MAP (RX-MAPLE), U$5.RXD0
USRRX1: HMMOD-UART.5 (TX), U$3.RX-MAP1 (RX-MAPLE1), U$5.RXD1
USRTX0: U$3.TX-MAP (TX-MAPLE), U$4.TX-MAP (TX-MAPLE), U$5.TXD0
USRTX1: HMMOD-UART.6 (RX), U$3.TX-MAP1 (TX-MAPLE1), U$5.TXD1
VCC: 1117.4 (OUT), C5.+, C6.1, C7.-, C10.2, C12.1, CHPD1.2, HMMOD-UART.1 (VCC), IC6.2 (OUT), IC6.TAB (OUT1), M1.J6.4 (VCC), NO_REGULATOR.1, RAW.2, RS485.8 (VCC), U$1.VCC, U$1.VCC1, U$3.VCC, U$3.VCC1, U$4.VCC, U$4.VCC1, U$5.3.3V, WLAN.VCC
VIN: F1.P$2 (2), J2.1-3 (3), J2.1-7 (7), J2.2-3 (3), J2.2-7 (7), NO_FUSE.2, U$2.TIP, X7.1

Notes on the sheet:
Power
HomeMatic
LAN
UART0
Debug
UART1
RX/TX from MAPLE Side !
8 7 6 5 4 3 2 1 Pair 4 1 2 gn3 ws3
RS485 Connectors
OneWire, etc.
Arduino Pro Mini
RS485
VDD-Config siehe 1Wire...
Terminierung mit Pull-Widerständen. Zwischen A und B 150 Ohm, von A 330 Ohm nach VCC, von B 330 Ohm nach GND. Damit wird er Bus auf HIGH gehalten wenn Teilnehmer passiv sind. AC-Widerstand ca. bei 120 Ohm (150 // (330+330)) = 122,2.
OneWire (or RS485 Connections)
USR-TCP232-E2 or hopefully T2
RS485 Arduino
Max 5,3V
3,3V Regulator

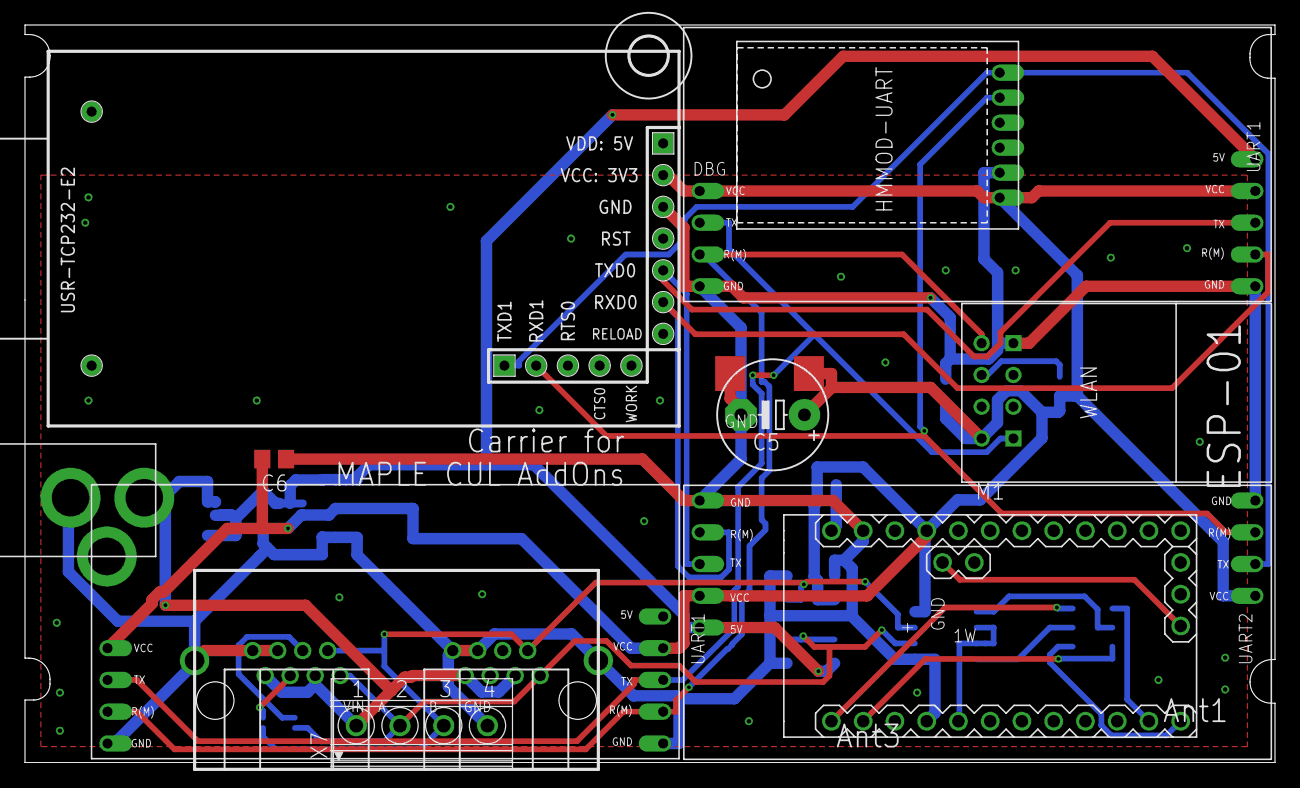
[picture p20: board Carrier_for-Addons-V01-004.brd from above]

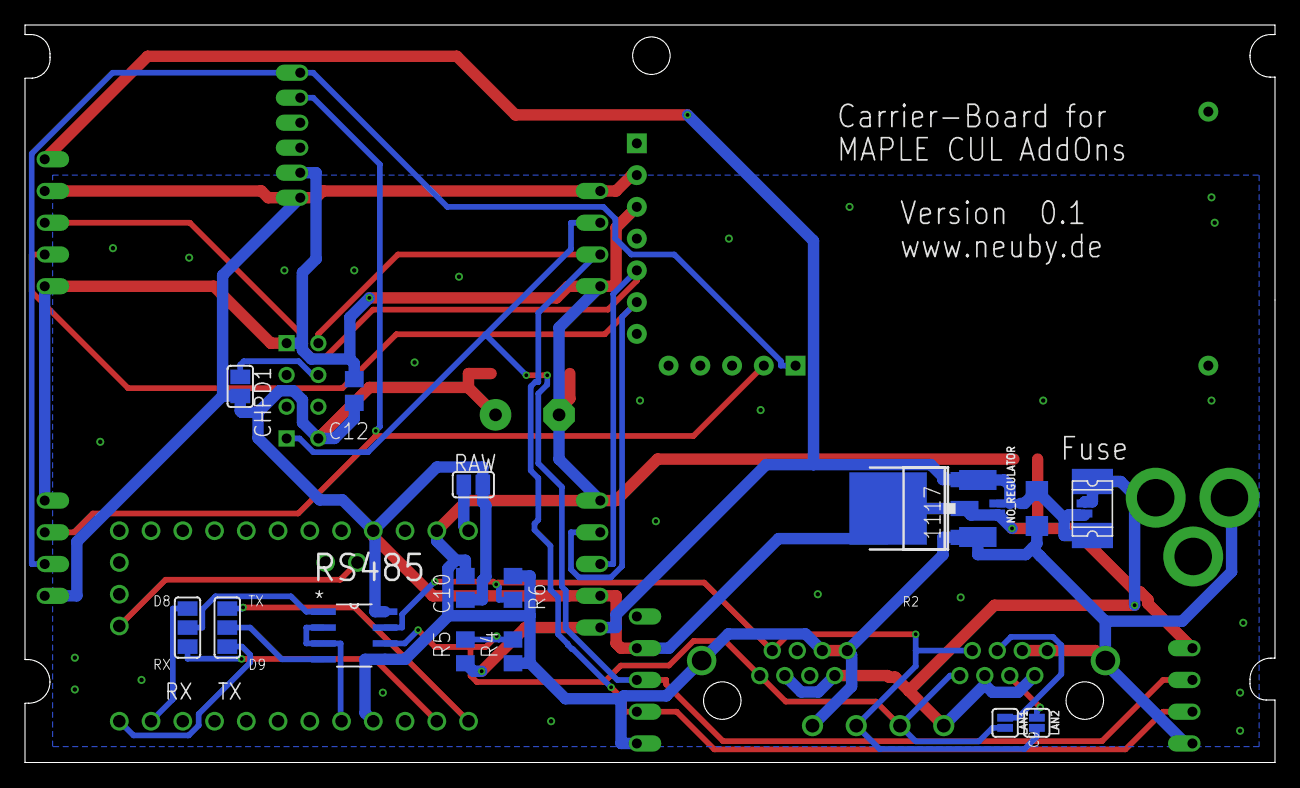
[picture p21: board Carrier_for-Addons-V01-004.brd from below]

Board: 2 copper layers, 100.0 x 59.0 mm, 32 parts (18 on the bottom side), 24 nets.

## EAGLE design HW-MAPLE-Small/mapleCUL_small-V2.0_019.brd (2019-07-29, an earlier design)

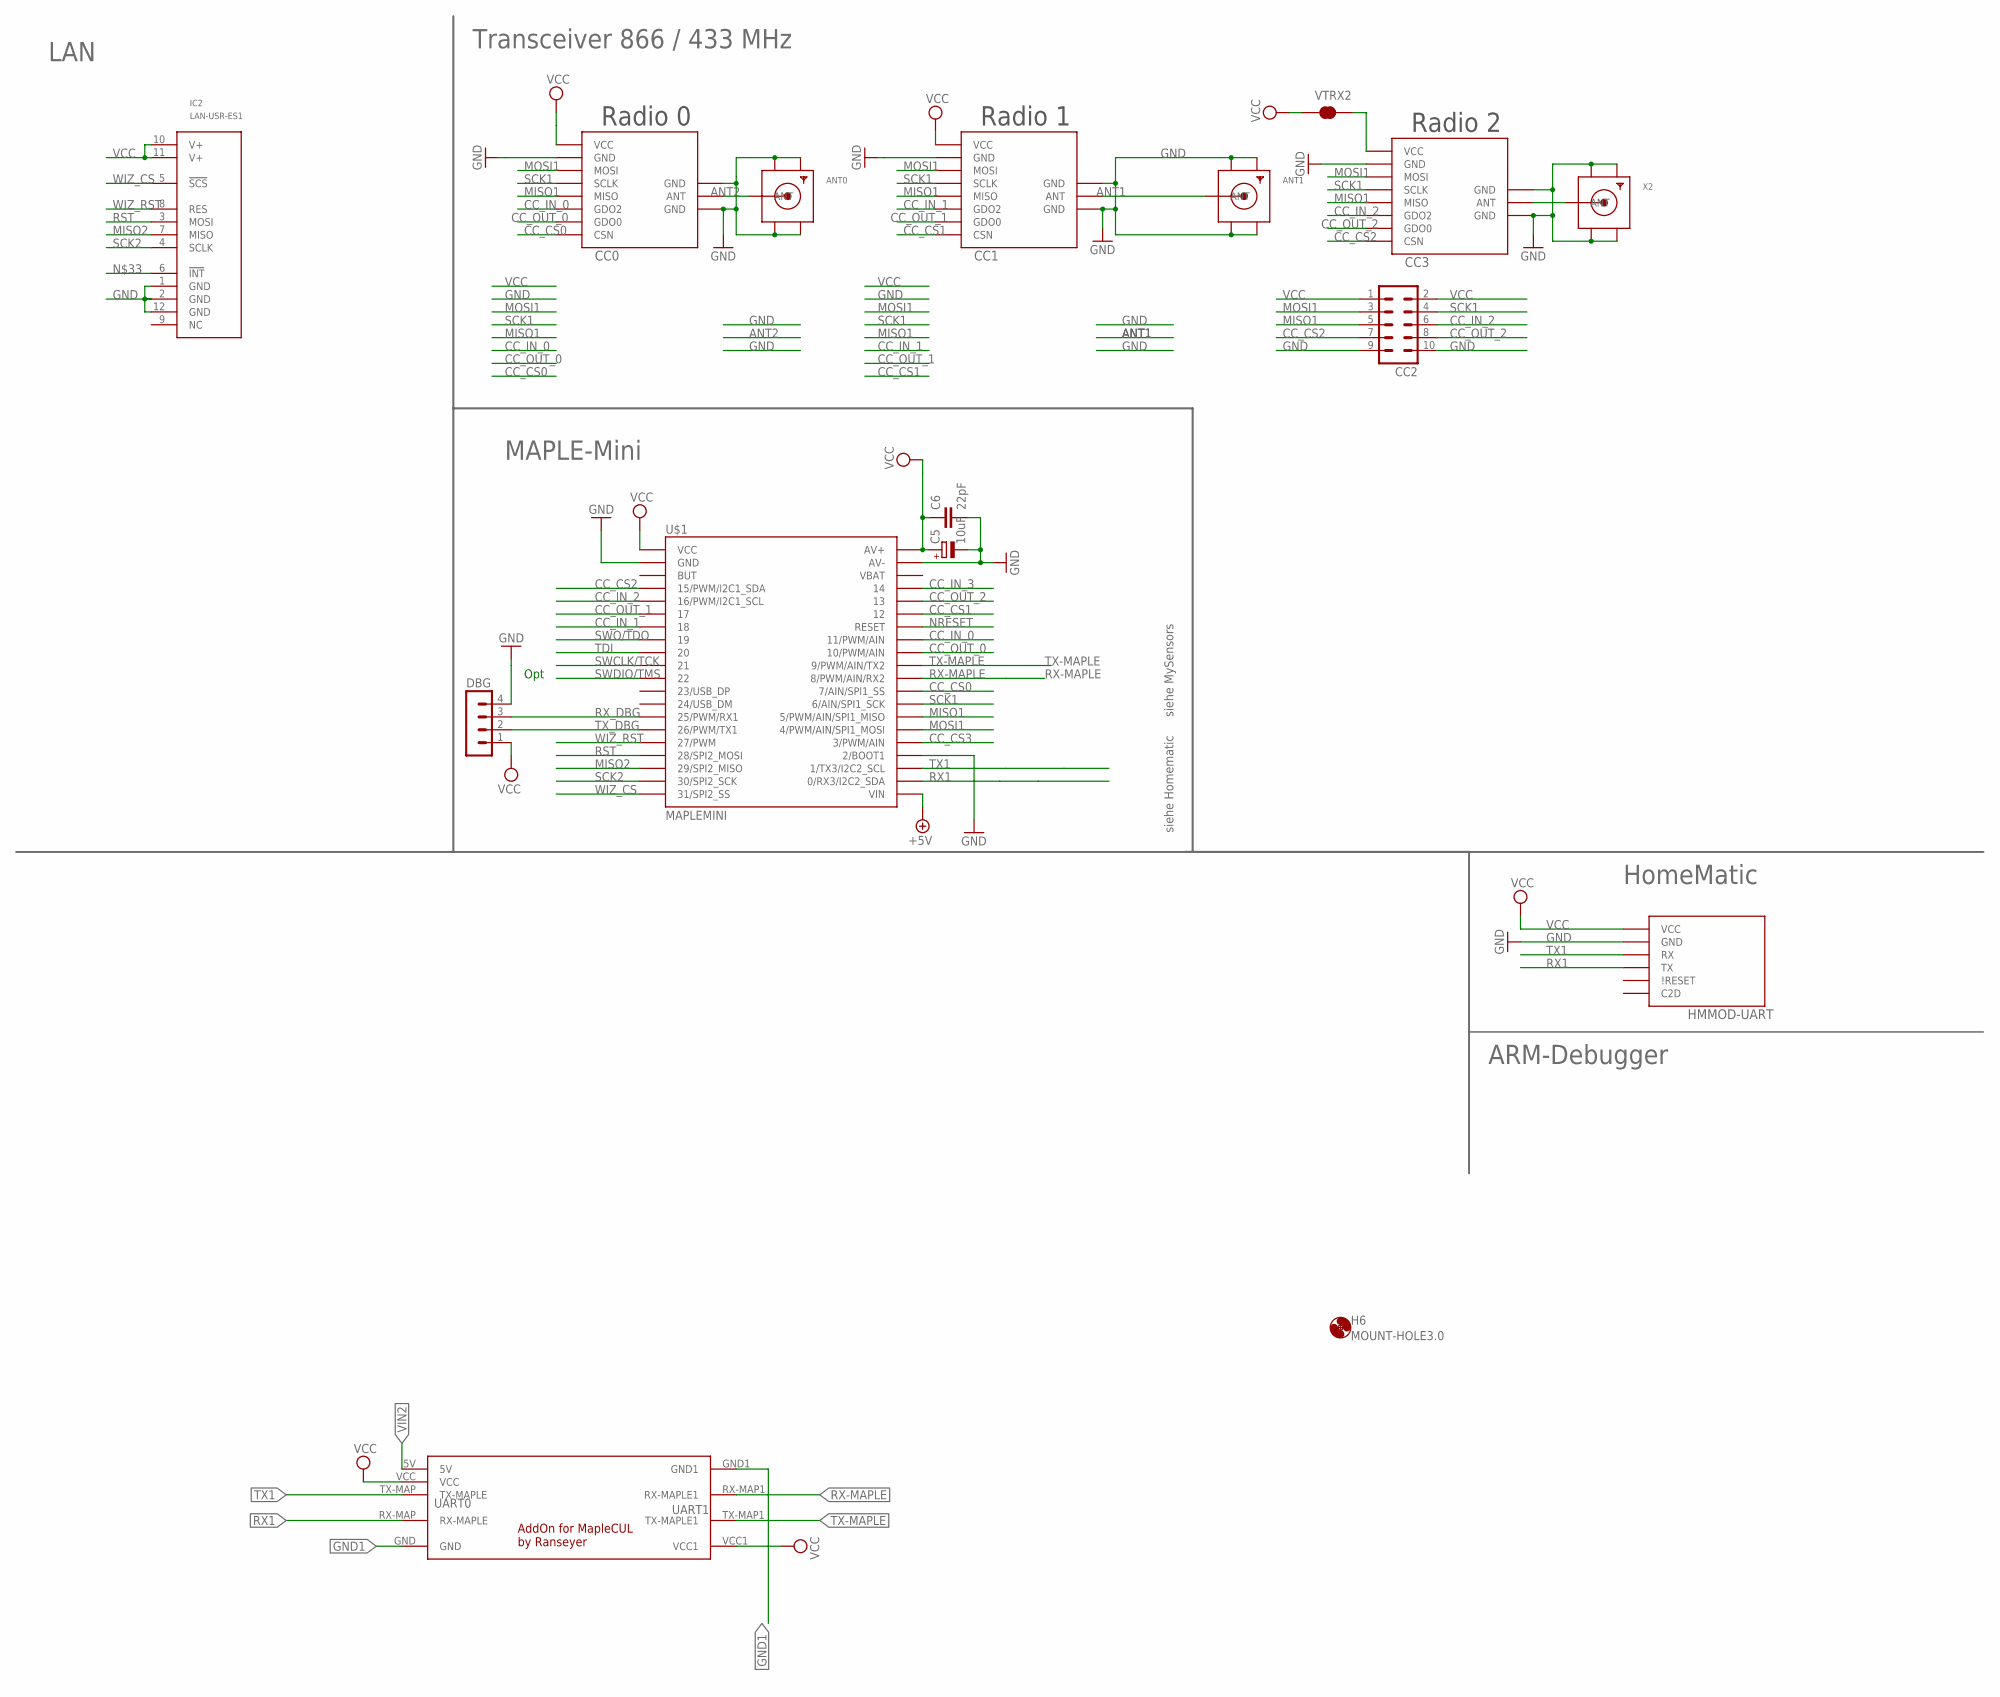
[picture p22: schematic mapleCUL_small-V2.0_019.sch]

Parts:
ANT0, ANT1: SMACONNECTOR_EDGE_UFL; SMA_EDGELAUNCH_UFL
C5: 10uF; R/2012-12W
C6: 22pF; C0805
CC0: CC1101; CC1101_MODULE1_SMD
CC1, CC3: CC1101_MODULE1SMD; CC1101_MODULE1_SMD
CC2: MA05-2
DBG: MA04-1
H6: MOUNT-HOLE3.0; 3,0
HMMOD-UART: HM-MOD-UARTDIL; HM-MOD-UART-DIL
IC2: LAN-USR-ES1; USR-ES1
U$1: MAPLEMINI; 20-DIP
U$3: MAPLE-CUL-ADDON-V01; MAPLE-CUL-V01
VTRX2: JUMPER-SMT_2_NC_TRACE_SILK; SMT-JUMPER_2_NC_TRACE_SILK
X2: SMACONNECTOR_EDGE; SMA_EDGELAUNCH

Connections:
+5V: U$1.21 (VIN)
ANT1: ANT1.P (ANT), CC1.ANT
ANT2: ANT0.P (ANT), CC0.ANT
ANT3: CC3.ANT, X2.P (ANT)
CC_CS0: CC0.CSN, U$1.29 (7/AIN/SPI1_SS)
CC_CS1: CC1.CSN, U$1.35 (12)
CC_CS2: CC2.7, CC3.CSN, U$1.4 (15/PWM/I2C1_SDA)
CC_CS3: U$1.25 (3/PWM/AIN)
CC_IN_0: CC0.GDO2, U$1.33 (11/PWM/AIN)
CC_IN_1: CC1.GDO2, U$1.7 (18)
CC_IN_2: CC2.6, CC3.GDO2, U$1.5 (16/PWM/I2C1_SCL)
CC_IN_3: U$1.37 (14)
CC_OUT_0: CC0.GDO0, U$1.32 (10/PWM/AIN)
CC_OUT_1: CC1.GDO0, U$1.6 (17)
CC_OUT_2: CC2.8, CC3.GDO0, U$1.36 (13)
GND: ANT0.GND@1 (GND1), ANT0.GND@2 (GND2), ANT0.GND@3 (GND3), ANT0.GND@4 (GND4), ANT1.GND@1 (GND1), ANT1.GND@2 (GND2), ANT1.GND@3 (GND3), ANT1.GND@4 (GND4), C5.-, C6.2, CC0.GND@0 (GND), CC0.GND@1 (GND), CC0.GND@2 (GND), CC1.GND@0 (GND), CC1.GND@1 (GND), CC1.GND@2 (GND), CC2.9, CC2.10, CC3.GND@0 (GND), CC3.GND@1 (GND), CC3.GND@2 (GND), DBG.4, HMMOD-UART.2 (GND), IC2.1 (GND), IC2.2 (GND), IC2.12 (GND), U$1.2 (GND), U$1.24 (2/BOOT1), U$1.39 (AV-), X2.GND@1 (GND4), X2.GND@2 (GND3), X2.GND@3 (GND2), X2.GND@4 (GND1)
GND1: U$3.GND, U$3.GND1
MISO1: CC0.MISO, CC1.MISO, CC2.5, CC3.MISO, U$1.27 (5/PWM/AIN/SPI1_MISO)
MISO2: IC2.7 (MISO), U$1.18 (29/SPI2_MISO)
MOSI1: CC0.MOSI, CC1.MOSI, CC2.3, CC3.MOSI, U$1.26 (4/PWM/AIN/SPI1_MOSI)
unnamed: CC3.VCC, VTRX2.2
NRESET: U$1.34 (RESET)
RST: IC2.3 (MOSI), U$1.17 (28/SPI2_MOSI)
RX1: HMMOD-UART.5 (TX), U$1.22 (0/RX3/I2C2_SDA), U$3.RX-MAP (RX-MAPLE)
RX-MAPLE: U$1.30 (8/PWM/AIN/RX2), U$3.RX-MAP1 (RX-MAPLE1)
RX_DBG: DBG.3, U$1.14 (25/PWM/RX1)
SCK1: CC0.SCLK, CC1.SCLK, CC2.4, CC3.SCLK, U$1.28 (6/AIN/SPI1_SCK)
SCK2: IC2.4 (SCLK), U$1.19 (30/SPI2_SCK)
SWCLK/TCK: U$1.10 (21)
SWDIO/TMS: U$1.11 (22)
SWO/TDO: U$1.8 (19)
TDI: U$1.9 (20)
TX1: HMMOD-UART.6 (RX), U$1.23 (1/TX3/I2C2_SCL), U$3.TX-MAP (TX-MAPLE)
TX-MAPLE: U$1.31 (9/PWM/AIN/TX2), U$3.TX-MAP1 (TX-MAPLE1)
TX_DBG: DBG.2, U$1.15 (26/PWM/TX1)
VCC: C5.+, C6.1, CC0.VCC, CC1.VCC, CC2.1, CC2.2, DBG.1, HMMOD-UART.1 (VCC), IC2.10 (V+), IC2.11 (V+), U$1.1 (VCC), U$1.40 (AV+), U$3.VCC, U$3.VCC1, VTRX2.1
VIN2: U$3.5V
WIZ_CS: IC2.5 (!SCS!), U$1.20 (31/SPI2_SS)
WIZ_RST: IC2.8 (RES), U$1.16 (27/PWM)

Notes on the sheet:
Radio 1
Radio 0
Opt
siehe Homematic
siehe MySensors
HomeMatic
MAPLE-Mini
Transceiver 866 / 433 MHz
LAN
ARM-Debugger
Radio 2
UART1
UART0

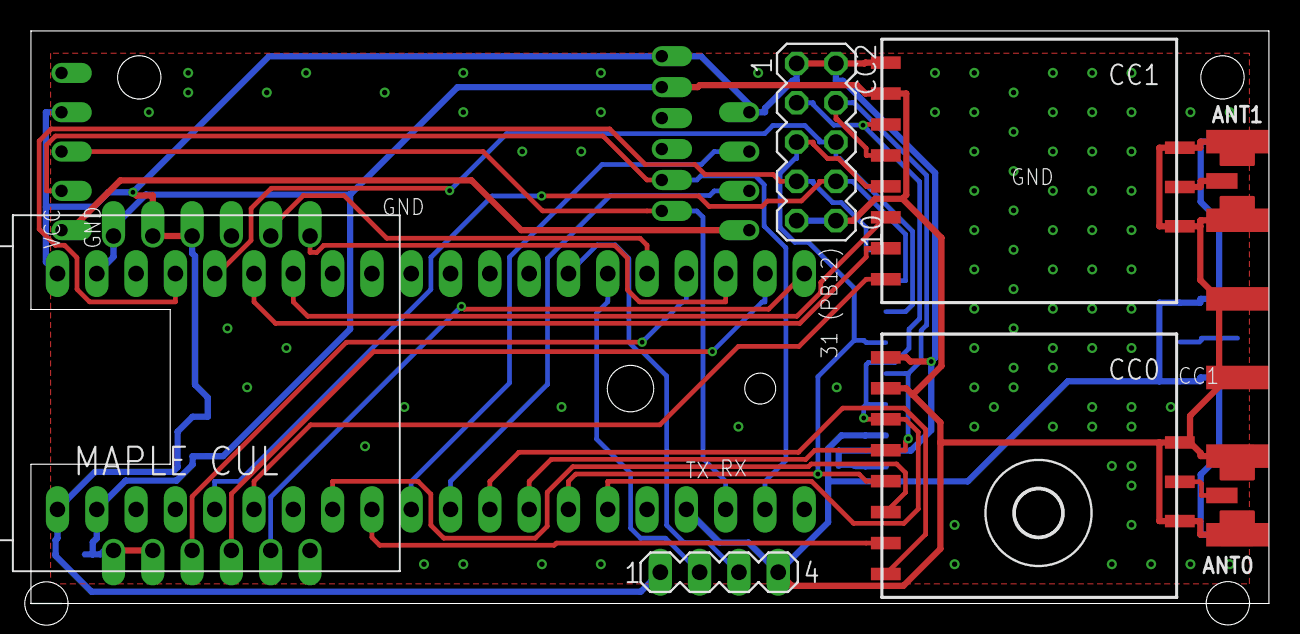
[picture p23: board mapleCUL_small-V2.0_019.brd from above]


Board: 2 copper layers, 80.0 x 37.0 mm, 16 parts (8 on the bottom side), 30 nets.

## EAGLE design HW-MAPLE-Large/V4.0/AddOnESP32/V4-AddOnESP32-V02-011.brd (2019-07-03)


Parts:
ANT2: PINHD-1X1; 1X01
C1: 2u2; C0805
C8: 330u; VISHAY_C
C9: 22u; C0805
CC0: CC1101; CC1101_MODULE1_SMD
R4, R5: 10k; M0805
R6: 10K; M0805
RST: DTSM-3
U3: ESP-WROOM-32
U$2: MAPLE-CUL-ADDON-V01; MAPLE-CUL-V01
X2: SMACONNECTOR_EDGE; SMA_EDGELAUNCH

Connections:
ANT0: ANT2.1, CC0.ANT, X2.P (ANT)
EN: C1.1, R4.1, RST.2, U3.3 (EN)
GND: C1.2, C8.-, C9.2, CC0.GND@0 (GND), CC0.GND@1 (GND), CC0.GND@2 (GND), R6.1, RST.1, U3.1 (GND), U3.15 (GND), U3.38 (GND), U3.GND, U$2.GND, U$2.GND1, X2.GND@1 (GND4), X2.GND@2 (GND3), X2.GND@3 (GND2), X2.GND@4 (GND1)
IO0: R5.1, U3.25 (IO0)
IO2: R6.2, U3.24 (IO2)
IO4: U3.26 (IO4)
IO5: CC0.GDO2, U3.29 (IO5)
IO6: U3.20 (CLK)
IO7: U3.21 (SDO)
IO8: U3.22 (SD1)
IO9: U3.17 (SD2)
IO10: U3.18 (SD3)
IO11: U3.19 (CMD)
IO12: U3.14 (IO12)
IO13: U3.16 (IO13)
IO14: U3.13 (IO14)
IO15: U3.23 (IO15)
IO16: CC0.GDO0, U3.27 (IO16)
IO17: CC0.CSN, U3.28 (IO17)
IO18: CC0.SCLK, U3.30 (IO18)
IO19: CC0.MISO, U3.31 (IO19)
IO21: U3.33 (IO21)
IO22: U3.36 (IO22)
IO23: CC0.MOSI, U3.37 (IO23)
IO25: U3.10 (IO25)
IO26: U3.11 (IO26)
IO27: U3.12 (IO27)
IO32: U3.8 (IO32)
IO33: U3.9 (IO33)
IO34: U3.6 (IO34)
IO35: U3.7 (IO35)
IO36: U3.4 (SENSOR_VP)
IO39: U3.5 (SENSOR_VN)
RX-MAPLE0: U$2.RX-MAP (RX-MAPLE)
RXD0: U3.34 (RXD0)
TX-MAPLE0: U$2.TX-MAP (TX-MAPLE)
TXD0: U3.35 (TXD0)
VCC: C8.+, C9.1, CC0.VCC, R4.2, R5.2, U3.2 (3V3), U$2.VCC, U$2.VCC1

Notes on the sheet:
mysX ESP32 1 VRAW 2 3V3 3 VCCio 4 GND 5 TXD0 6 RXD0 7 EN 8 IO27 9 IO0 10 IO2 11 IO4 12 IO25 13 IO22 14 IO21 15 SENSOR_VN 16 IO15 17 IO13 18 IO12 19 IO14 20 IO26 21 IO34 22 IO35
PB0 auch am mysX
Radio1
Radio 2 alternativ
CC1101
Wenn man die Pins von dem MYSx Stecker: 3.3V, GND, RX, TX, EN und GPIO00 nimmt und einen Standad USB Programmer (z.B. einen FDDI um 1,60€) nimmt und den EN auf RTS und GPIO00 auf DTR verbindet. Dann setzt der Flasher den Chip automatisch in den Flash Mode, führt den Flash durch und macht den Reset 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
Alternativ
Core
Power-Supply



Board: 2 copper layers, 48.0 x 29.0 mm, 12 parts (8 on the bottom side), 12 nets.

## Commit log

2016-12-20 1st draft
    [MAPLE-CUN-V016-routed.brd, MAPLE-CUN-V016-routed.sch]
2016-12-21 Large Version V1
    [MAPE-CUN-Large-010.brd, MAPE-CUN-Large-010.sch]
2016-12-27 Large Version V2
    [MAPE-CUN-Large-001-not_used.brd, MAPE-CUN-Large-001-not_used.sch, MAPE-CUN-Large-016.brd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]
2016-12-28 Production Gerber
    [MAPE-CUN-Large-018.brd, MAPE-CUN-Large-018.sch, MAPLE-CUN-V017-routed.brd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]
2017-02-02 Fix Large-PCB; Adapter for Stamps
    [Adapter-Stamps-001.brd, Adapter-Stamps-001.sch, MAPE-CUN-Large-001-not_used.brd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]
2017-02-02 Moved LAN "Port"
    [MAPE-CUN-Large-022.brd, MAPE-CUN-Large-022.dsn, MAPE-CUN-Large-022.sch]
2017-02-06 + mySensors
    [MAPE-CUN-Large-022-Input.brd, MAPE-CUN-Large-022-Input.sch, MAPE-CUN-Large-032.brd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]
2017-02-06 optimized v2
    [MAPE-CUN-Large-022-Input.brd, MAPE-CUN-Large-022-Input.sch, MAPE-CUN-Large-033.brd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]
2017-02-06 Folgende Änderungen: - bisheriges Layout im Raster 1 mm nach oben verschoben - Umrandung Gehäuse eingefügt - 433 MHz Modul im Schaltplan eingefügt - Arduino pro mini als Minimalversion in den Schaltp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
    [mapleCUx_large_034.brd, mapleCUx_large_034.sch]
2017-02-07 Large A 1.2-Version
    [MAPE-CUN-Large-033.brd, MAPE-CUN-Large-033.sch, mapleCUx_large_035-ok.brd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]
2017-02-08 v39, last complete file-set
    [mapleCUx_large_039.brd, mapleCUx_large_039.sch]
2017-02-08 Medium V001
    [mapleCUx_Med-001.brd, mapleCUx_Med-001.sch]
2017-02-08 Medium V001
    without Arduino-Board
    [mapleCUx_Med-001.brd, mapleCUx_Med-001.sch]
2017-02-08 Cleanup + Restore V41-Schematic
    [mapleCUx_large_034.brd, mapleCUx_large_034.sch, mapleCUx_large_039.brd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]
2017-02-09 mapleCUx_003: - anderes Gehäuse - Bibliotheken für W5100 und W5500 Modul - Schaltplan aktualisiert - erste Platzierung Gruß PeMue
    [mapleCUx_med_003.brd, mapleCUx_med_003.sch]
2017-02-14 Test in new case
    [mapleCUx_med_004-test.brd, mapleCUx_med_004-test.sch]
2017-02-15 U.FL Connectors possible
    [mapleCUx_large_042b.brd, mapleCUx_large_042b.sch]
2017-02-16 New Version+ Cleanup
    [MAPLE-CUN-V017-routed.brd, MAPLE-CUN-V017-routed.sch, MAPLE-CUN-V023.brd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]
2017-02-18 Medium Test1
    [mapleCUx_Med-001.brd, mapleCUx_med_004-test.brd, mapleCUx_med_004-test.sch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]
2017-02-27 v50 1Wire -draft
    [mapleCUx_large_050.brd, mapleCUx_large_050.sch, mapleCUx_med_011.brd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]
2017-02-27 v52 1Wire v2
    [mapleCUx_large_052.brd, mapleCUx_large_052.sch]
2017-02-28 Large 056
    [mapleCUx_large_056.brd, mapleCUx_large_056.sch]
2017-03-01 geänderte Version 57: - Beschriftungen angepasst (top/bottom) offen: - rechts über der Platine: Beschriftungen ggf. auf die Platine verschieben oder löschen - CC1101 Modul hat Beschriftung >Label -> 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
    [mapleCUx_large_057.brd, mapleCUx_large_057.sch]
2017-03-02 Large 067
    [mapleCUx_large_056.brd, mapleCUx_large_057.brd, mapleCUx_large_057.sch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]
2017-03-02 Large 069 Maple moved to Bottom...
    [mapleCUx_large_068-Maple-unten.brd, mapleCUx_large_068-Maple-unten.sch, mapleCUx_large_069-Maple-unten.dsn]
2017-03-03 Large 082 Maple moved to Top...
    [mapleCUx_large_067.brd, mapleCUx_large_068-Maple-unten.sch, mapleCUx_large_069-Maple-unten.dsn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]
2017-03-03 Large 083 Antennas rerouted
    [mapleCUx_large_083.brd, mapleCUx_large_083.sch]
2017-03-03 Large 084 LAN lib fixed (dimension)
    [mapleCUx_large_084.brd, mapleCUx_large_084.sch]
2017-03-03 MAPLE wieder unten
    [mapleCUx_large_085-MAPLE-unten.brd, mapleCUx_large_085-MAPLE-unten.sch]
2017-03-04 Cleanup + Stripped Version
    [mapleCUx_large_084.brd, mapleCUx_large_088-Stripped.brd, mapleCUx_large_088-Stripped.sch]
2017-03-04 Small Fixes + other RX+TX Pins at Arduino
    [mapleCUx_large_085.brd, mapleCUx_large_085.sch, mapleCUx_large_088-Stripped.brd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]
2017-03-05 Charge4 in Archiv
    [mapleCUx_large_085.brd, mapleCUx_large_085.sch, mapleCUx_large_088-Stripped.brd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]
2017-03-09 Restore Small-Version
    [MAPLE-CUN-V017-routed.brd, MAPLE-CUN-V017-routed.sch, MAPLE-CUN-V023.brd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]
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2017-04-09 Large 100 - small Optimisations
    -W5500 an Rand
    -UART mehr an Rand
    -ohne 1Wire
    - CC0+1 nicht mehr steckbar, nur Stamp
    -MAPLE oben, ober falls unter Buttons per Loch erreichbar
    [mapleCUx_large_100.brd, mapleCUx_large_100.sch]
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2017-04-22 1.2 Large - more docu
    [mapleCUx_med_018.brd, mapleCUx_med_018.sch, mapleCUx_med_019.brd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]
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2017-10-17 V3.0 (stripped) plus Addon
    [Addon-mapleCUx_HM-RFM69-012.brd, Addon-mapleCUx_HM-RFM69-012.sch, Addon-mapleCUx_OneWire-RS485-003.brd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]
2017-12-09 Pictures + Fixes
    [Addon-mapleCUx_HM-RFM69-050.brd, Addon-mapleCUx_HM-RFM69-050.sch]
2017-12-15 V3 Update + AddOns
    V3 => 3.1 some more Cs
    Addons:
    -OneWire Beta
    -RFM69: Module with other / better Footprint
    [Addon-mapleCUx_HM-RFM69-012.brd, Addon-mapleCUx_HM-RFM69-012.sch, Addon-mapleCUx_HM-RFM69-V10-005.brd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]
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2018-06-11 Large 3.3 + AddOn for Raspi-UART-Modules
    [Addon-mapleCUx_Raspi-3V3-UART-Adapter-008.brd, Addon-mapleCUx_Raspi-3V3-UART-Adapter-008.sch, mapleCUx_large_330-007.brd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]
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2018-07-29 Case from Thingiverse; Zigbee/RaspiAddOn
    [Addon-mapleCUx_Raspi-3V3-UART-CC2530-V012.brd, Addon-mapleCUx_Raspi-3V3-UART-CC2530-V012.sch, MapleCUN_Gehäuse.f3d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]
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2018-08-08 Zigbee TX Fix
    [Addon-mapleCUx_Raspi-3V3-UART-CC2530-V02-02.brd, Addon-mapleCUx_Raspi-3V3-UART-CC2530-V02-02.sch]
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2019-02-17 V3.5
    2 more Connections to ESP
    Port for flashing, 1Wire
    [Addon-LAN-WLAN-without-MAPLE-V01-001.brd, Addon-LAN-WLAN-without-MAPLE-V01-001.sch, Addon-mapleCUx_HM-RFM69-RFM95-V15-001-TX-Fix.brd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]
2019-02-22 V3.5 and 1W Stamp
    [1WireStamp-V01-006.brd, 1WireStamp-V01-006.sch, mapleCUx_large_350-010.brd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]
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2019-05-29 Fix for old RFM69 AddOn + Docu
    [Addon-mapleCUx_HM-RFM69-RFM95-V15-003-TX-Fix.brd, Addon-mapleCUx_HM-RFM69-RFM95-V15-003-TX-Fix.sch, V4-AddOnSduino-V003.brd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]
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

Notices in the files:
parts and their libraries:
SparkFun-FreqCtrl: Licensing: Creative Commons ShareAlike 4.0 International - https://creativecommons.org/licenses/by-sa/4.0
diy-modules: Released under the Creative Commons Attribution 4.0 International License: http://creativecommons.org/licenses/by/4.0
